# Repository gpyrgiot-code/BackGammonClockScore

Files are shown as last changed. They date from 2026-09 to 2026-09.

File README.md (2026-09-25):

# Backgammon Match Clock

A portable ESP32-S3 backgammon match clock and scoreboard built for an Elecrow
CrowPanel 5-inch 800x480 RGB touchscreen. The firmware combines tournament
scoring, three clock systems, Crawford tracking, physical controls, battery
monitoring, an RTC, player customization, match history, and day/night themes.

## Highlights

- 800x480 capacitive touchscreen interface
- Two player clocks and touch-adjustable scores
- Physical Player A, Player B, and Play/Pause buttons
- Match targets from 1 through 21 points (odd values)
- Timer by game or timer for the complete match
- Simple delay, Bronstein delay, and Fischer increment
- Crawford and post-Crawford tracking
- Standard score or Points to Win display
- Editable player names and checker-color scorecards
- Persistent settings stored in ESP32 preferences
- Match history with names, score, and RTC date
- MAX17048 battery monitoring and DS3231 date/time
- Day and night display themes
- Light-red timer warning at 1:30 or less
- Optimized custom GFX fonts and startup splash image

## Target Hardware

The firmware targets the Elecrow ESP32-S3 CrowPanel HMI with:

- ESP32-S3
- 8 MB OPI PSRAM
- 800x480 RGB-parallel display
- GT911 capacitive touch controller
- PCA9557 onboard I/O expander

External hardware used by the complete build:

- PCF8575 16-bit I2C GPIO expander
- MAX17048 LiPo fuel gauge
- DS3231 real-time clock
- Three normally-open momentary push buttons
- One-cell LiPo battery and a suitable protected charging/power circuit

The MAX17048 measures the battery but does not charge it. Use a charging and
power-management circuit designed for the battery chemistry and load. Verify
battery polarity before applying power; reversing BAT+ and BAT- can damage the
module, battery, or ESP32.

## Project Layout

```text
BackgammonMatchClock/
   |-- BackgammonMatchClock.ino
   |-- splash_image.h
   |-- splash4.png
   |-- 7segment48pt7b_numbers.h
   |-- collegeb96pt7b_numbers.h
   |-- FreeSansBold48pt7b_numbers.h
   |-- FreeSans12pt7b.h
```

The firmware uses a custom RGB565 renderer built on the ESP-IDF RGB LCD
peripheral. It does not require LVGL or an external TFT library.

## I2C Bus

The shared I2C bus uses:

| Signal | ESP32-S3 pin |
|---|---:|
| SDA | GPIO 19 |
| SCL | GPIO 20 |
| Logic supply | 3.3 V |
| Ground | GND |

Configured devices:

| Device | Address | Purpose |
|---|---:|---|
| PCA9557 | `0x18`-`0x1F` | CrowPanel initialization/reset control |
| PCF8575 | `0x20`-`0x27` | Physical clock buttons |
| MAX17048 | `0x36` | Battery voltage and state of charge |
| GT911 | Usually `0x5D` | Capacitive touch |
| DS3231 | `0x68` | Date and time |

All I2C modules share SDA, SCL, 3.3 V, and GND. An I2C splitter is only a
parallel connection hub; each device remains on the same bus and needs a unique
address.

## Physical Buttons

The PCF8575 ports are active-low inputs. Connect one terminal of each
normally-open button to its PCF8575 port and the other terminal to GND.

| Function | PCF8575 port |
|---|---:|
| Play/Pause | P00 |
| Player A clock | P01 |
| Player B clock | P07 |

Four-leg tactile switches contain two internally connected pairs. Use one leg
from each opposite electrical side. Confirm continuity with a multimeter before
soldering.

The firmware also supports a direct button on GPIO 38 for compatibility with the
earlier one-button prototype.

## Display Connections

The built-in RGB panel uses these fixed signals:

| Signal | GPIO |
|---|---|
| Backlight | 2 |
| D0-D15 | 8, 3, 46, 9, 1, 5, 6, 7, 15, 16, 4, 45, 48, 47, 21, 14 |
| DE | 40 |
| VSYNC | 41 |
| HSYNC | 39 |
| PCLK | 0 |

Do not reuse these pins for external controls.

## User Interface

### Main screen

The main screen contains:

- Battery status, elapsed match time, date, and time
- Player names and clock values
- Player scorecards
- Play Game/Pause Game control
- End Game and End Match controls
- Match target, game counter, and Crawford state
- Log and Settings buttons

The name bars use each player's selected checker color. When either timer reaches
1:30, its background becomes light red as a low-time warning.

### Touch controls

- Tap Player A's timer to finish A's turn and start Player B's clock.
- Tap Player B's timer to finish B's turn and start Player A's clock.
- Tap Play Game to start or resume; tap Pause Game to pause.
- Swipe up on a scorecard to add one point.
- Swipe down on a scorecard to remove one point.
- Tap a player name while paused to edit the name and checker color.
- Tap End Game to stop the current game without resetting the match clocks.
- Tap End Match to confirm and record the result.
- After a match ends, End Match becomes Reset.

Scores can only be changed while the clock is paused or after a game ends.

### Settings

Settings includes:

- Match target: 1, 3, 5, ... 21
- Time per game in 30-second steps
- Bonus or delay duration
- Timer scope: Game or Match
- Timing mode: Simple, Bronstein, or Fischer
- Appearance
- RTC clock/date setup
- Start Match and End Match

### Appearance

Appearance currently provides:

- Night or Day color theme
- Score or Points to Win display

Points to Win is a display-only calculation:

```text
points to win = match target - actual player score
```

Stored scores, Crawford logic, match winner detection, and history remain based
on the actual score.

### Match log

The Log screen stores up to eight completed matches. Each entry includes the RTC
date, both player names, and the final score. The log is stored in nonvolatile
ESP32 preferences and can be cleared from the Log screen.

## Timing Modes

### Simple delay

The reserve clock does not visibly decrease during the delay. Only time used
beyond the configured delay is deducted.

```text
deduction = max(0, elapsed turn time - delay)
```

Unused delay is not added to the reserve.

### Bronstein delay

The clock counts down immediately. When the player presses the clock, elapsed
time up to the configured delay is refunded. The final reserve deduction is the
same as Simple delay, but the live display behaves differently.

```text
refund = min(elapsed turn time, delay)
```

### Fischer increment

The clock counts down during the turn. Pressing the clock adds the configured
increment to that player's reserve.

```text
new reserve = old reserve - elapsed turn time + increment
```

Players can gain reserve time by moving faster than the increment.

### Timer scope

- **Game:** each player's timer resets when a new game begins.
- **Match:** each player's initial reserve equals time per game multiplied by
  the match target and carries across games.

If a player reaches zero, the timeout screen identifies that player. Applying
the penalty point remains a manual scoring action.

## Crawford Rule

When either player reaches one-away and Crawford has not already been used, the
next game is marked `CRAWFORD` and the doubling cube is disabled. After that
game, the display changes to `POST CRAWFORD` and the cube is enabled for all
remaining games.

## Fonts and Splash Image

The sketch uses trimmed GFX font headers to reduce flash use:

- `7segment48pt7b_numbers.h`: timer digits and colon
- `collegeb96pt7b_numbers.h`: score digits
- `FreeSansBold48pt7b_numbers.h`: match target digits
- `FreeSans12pt7b.h`: interface text

The splash image is stored as RGB565 data in `splash_image.h`. Its source is
`splash4.png`.

## Building with Arduino IDE

### Requirements

- Arduino IDE 2.x
- Espressif Systems ESP32 board package
- USB data cable

Open:

```text
BackgammonMatchClock/BackgammonMatchClock.ino
```

Recommended board settings:

| Setting | Value |
|---|---|
| Board | ESP32S3 Dev Module |
| PSRAM | OPI PSRAM |
| USB CDC On Boot | Disabled or Default |
| USB Mode | Hardware CDC/JTAG or Default |
| Upload Speed | 115200 |

PSRAM is mandatory. An 800x480 RGB565 framebuffer requires more memory than the
ESP32-S3's internal RAM can provide. If Serial Monitor reports `PSRAM found: no`,
select OPI PSRAM and upload again.

### Upload

1. Connect the CrowPanel over USB.
2. Select its `/dev/cu.usbserial...` port.
3. Compile and upload.
4. Open Serial Monitor at 115200 baud.

If automatic upload does not begin, hold BOOT, start the upload, and release BOOT
when `Connecting...` appears. Press RESET after a successful upload if needed.

Uploads at 921600 can connect successfully and then fail with `The chip stopped
responding`. Use 115200 for reliable flashing.

## Arduino CLI

From the repository directory:

```sh
sh scripts/compile-arduino.sh
sh scripts/upload-arduino.sh /dev/cu.usbserial-XXXXX
```

Replace the port with the result from:

```sh
arduino-cli board list
```

The equivalent compile target is:

```sh
arduino-cli compile \
  --fqbn esp32:esp32:esp32s3:PSRAM=opi,CDCOnBoot=default,USBMode=default \
  BackgammonMatchClock
```

## PlatformIO

The repository includes `platformio.ini`:

```sh
pio run
pio run -t upload
pio device monitor -b 115200
```

Arduino IDE/CLI is the primary tested workflow for the CrowPanel hardware.

## Wokwi

`WokwiMatchClock` is a generated compatibility target. Wokwi does not model the
CrowPanel RGB panel, GT911, PCA9557, PCF8575, MAX17048, or DS3231 exactly, so it
uses display and input substitutions.

After firmware changes, regenerate the Wokwi copy with:

```sh
node scripts/sync-wokwi.mjs
```

Do not place both the generated `sketch.ino` and hardware `.ino` in one Wokwi
project because Arduino will compile both and report duplicate definitions.

The ESP32 binary cannot run directly on macOS because it contains ESP32-S3
machine code and hardware drivers. A native desktop simulator is not yet
included.

## Serial Diagnostics

Use Serial Monitor at 115200 baud. A healthy boot should report:

- `PSRAM found: yes`
- PCA9557 found and initialized
- PCF8575 found, if connected
- MAX17048 found at `0x36`, if connected
- DS3231 found at `0x68`, if connected
- GT911 found, normally at `0x5D`
- `esp_lcd_new_rgb_panel: 0`
- `esp_lcd_panel_reset: 0`
- `esp_lcd_panel_init: 0`

P00 Play/Pause presses also print a diagnostic line with the current mode and
clock state.

## Troubleshooting

### White or blank screen

- Confirm PSRAM is set to OPI PSRAM.
- Verify Serial reports `PSRAM found: yes`.
- Confirm the RGB panel initialization calls return `0`.
- Use a stable USB power source and cable.
- Check that the PCA9557 appears on the I2C scan.

### Touch is not detected

- Confirm the GT911 appears in the I2C scan.
- Check SDA, SCL, power, and ground.
- Make sure no external device is holding the shared I2C bus low.

### PCF8575 buttons are not detected

- Confirm the expander appears between `0x20` and `0x27`.
- Connect each button between its assigned P port and GND.
- Solder module headers; loose unsoldered pins are not electrically reliable.
- Verify address jumpers do not conflict with another device.

### Battery percentage is missing or unstable

- Confirm the MAX17048 appears at `0x36`.
- Verify battery polarity and solder joints.
- Allow the gauge time to settle after reconnecting the cell.
- The firmware performs a MAX17048 quick-start during initialization.
- Charging may be inferred from a rising voltage/state-of-charge trend unless a
  dedicated charger status pin is added.

### RTC is missing or the log says DATE UNSET

- Confirm the DS3231 appears at `0x68`.
- Set date and time through Settings > Clock.
- Check the RTC backup battery if time is lost when power is removed.

### Upload fails after changing baud rate

Select 115200 upload speed, reconnect USB, and retry. Temporarily disconnecting
external modules can help diagnose power or bus issues while flashing.

### Duplicate or unreadable Serial output

The firmware writes diagnostics to both available serial interfaces for board
compatibility. Use 115200 baud. Boot ROM characters may briefly appear garbled
if the monitor opens during reset.

## Enclosure

The `BackgammonMatchClock/case` directory contains enclosure work for a sloped
desktop clock body with a front display opening and top-mounted player and
Play/Pause buttons. Verify dimensions against the physical hardware before
printing or machining.

## Safety

- Use a protected single-cell LiPo setup designed for charging and load sharing
  if the clock operates while charging.
- Never connect a LiPo directly to a 5 V input unless the board documentation
  explicitly permits it.
- Do not reverse battery polarity.
- Do not power I2C signal pull-ups above 3.3 V.
- Place a physical power switch in the battery or regulated load path according
  to the charger/power-path design.

## Current Status

The firmware compiles for ESP32-S3 with OPI PSRAM and currently uses about 47%
of program flash and 7% of internal dynamic memory. The project remains under
active development, with Appearance prepared for additional layouts and themes.

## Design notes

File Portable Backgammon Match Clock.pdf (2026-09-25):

# Portable Backgammon Match Clock

# Current Firmware Code Walkthrough

# ESP32-S3 CrowPanel 5-inch / 800x480 / GT911

Source | BackgammonMatchClock.ino
Source size | 4,357 lines at publication
Firmware label | lcd-refresh-2026-06-07
Manual edition | September 2026 update

Hardware, wiring, state model, timing rules, UI, persistence, diagnostics, and complete source

Backgammon Match Clock | Current Firmware Walkthrough

# Contents

1 Purpose and Scope | 3
2 System Architecture | 3
3 Hardware Contract | 4
4 State Model | 5
5 Clock Engine | 5
6 Scoring and Match Lifecycle | 6
7 User Interface | 6
8 Touch and Button Input | 7
9 Rendering Pipeline | 7
10 Battery, Charging, and RTC | 8
11 Persistence and Match Log | 8
12 Startup and Diagnostics | 8
13 Build and Upload | 8

14 Maintenance Guide | 9
15 Known Limitations | 9
16 Top-Level Function Inventory | 10
A Complete Current Firmware Source | 11

# 1 Purpose and Scope

This document explains the current portable backgammon match clock firmware as an engineering and maintenance reference. It supersedes the earlier V2.0 PDF, whose source snapshot was 4,104 lines and predated several user-interface and hardware changes. The present sketch is a single Arduino translation unit with custom display, touch, game, timing, persistence, and peripheral code.

## The clock provides:

- two player clocks, scores, editable names, and checker colors;
- touch control plus Player A, Player B, and Play/Pause physical buttons;
- Simple delay, Bronstein delay, and Fischer increment;
- timer-by-game and timer-by-match scopes;
- Crawford and post-Crawford match state;
- day/night themes and Score/Points-to-Win views;
- a MAX17048 fuel gauge, DS3231 RTC, and eight-entry match log;

## - a compiled RGB565 splash image and optimized numeric fonts; and

- direct ESP-IDF RGB-panel rendering without LVGL.

# 2 System Architecture

The firmware uses an event-and-state architecture. Input handlers mutate the model, model transitions mark the display dirty, and rendering rebuilds the appropriate screen. Time-sensitive timer regions can be refreshed separately from the rest of the interface.

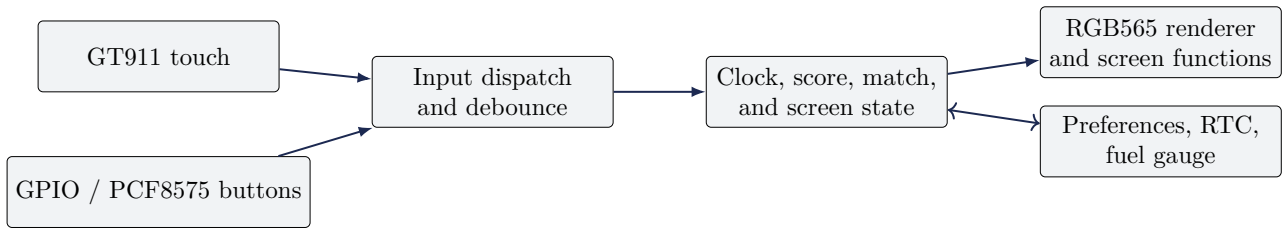
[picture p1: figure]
GT911 touch; GPIO / PCF8575 buttons; Input dispatch and debounce; Clock, score, match, and screen state; RGB565 renderer and screen functions; Preferences, RTC, fuel gauge

# 2.1 Main runtime cycle

setup() initializes serial diagnostics, button objects, I2C peripherals, the RGB panel, splash screen, preferences, match state, and RTC cache. The order is deliberate: the onboard PCA9557 and touch-reset path must be ready before the GT911 and display are used.

## loop() performs five recurring jobs:

1. poll touch and physical buttons;
2. update the active clock when in match mode;
3. commit delayed preference writes;

## 4. evaluate inactivity sleep; and

5. refresh either the whole screen or only the timer panels.

The one-second timer refresh and dirty-screen redraw split reduces visible flashing compared with repainting the entire 800x480 framebuffer continuously.

# 3 Hardware Contract

# 3.1 Target board

The target is the Elecrow CrowPanel ESP32-S3 5-inch HMI with an 800x480 RGB-parallel panel, GT911 capacitive touch controller, onboard PCA9557, and 8 MB OPI PSRAM. PSRAM is mandatory because a full RGB565 frame requires approximately 768,000 bytes before additional buffers and application state.

# 3.2 Shared I2C bus

Device or signal | Pin/address | Purpose
SDA | GPIO 19 | Shared data line; use 3.3 V pull-ups only.
SCL | GPIO 20 | Shared clock line.
PCA9557 | 0x18-0x1F | CrowPanel reset and board initialization.
PCF8575 | 0x20-0x27 | Three active-low physical buttons.
MAX17048 | 0x36 | Single-cell battery voltage and state of charge.
GT911 | normally 0x5D | Capacitive touch coordinates.
DS3231 | 0x68 | Date and time for the status bar and match log.

All devices share SDA, SCL, 3.3 V, and GND. A passive I2C splitter duplicates connectors; it does not create separate buses or resolve address conflicts.

# 3.3 Physical buttons

The PCF8575 is initialized with all port bits high. Each normally-open switch connects its assigned port to ground when pressed.

Function | PCF8575 port | Runtime action
Play/Pause | P00 | Start a game, pause, or resume.
Player A | P01 | End A’s turn and start B’s clock.
Player B | P07 | End B’s turn and start A’s clock.

GPIO 38 remains as compatibility support for the earlier single-button wiring. The direct Player B and score/menu pins use 255, which is the sketch’s disabled-pin sentinel.

# 3.4 RGB display pins

Role | GPIO assignment
D0-D15 | 8, 3, 46, 9, 1, 5, 6, 7, 15, 16, 4, 45, 48, 47, 21, 14
DE / VSYNC / HSYNC / PCLK | 40 / 41 / 39 / 0
Backlight | 2

These pins belong to the panel and must not be reused by external controls. The firmware requests a 20 MHz pixel clock and ten-line bounce buffer.

# 4 State Model

# 4.1 Device modes

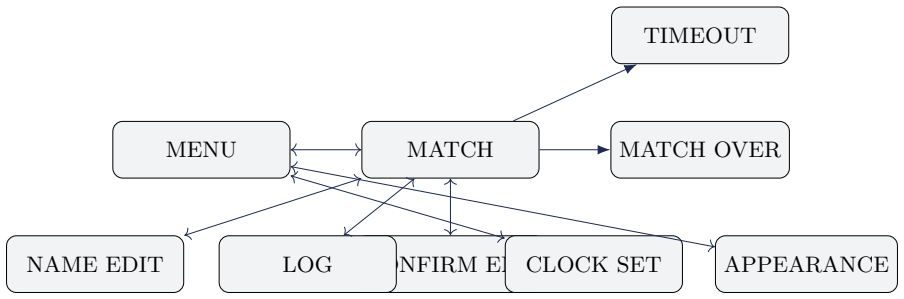
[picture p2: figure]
MENU; MATCH; MATCH OVER; TIMEOUT

NAME EDIT | LOG | CONFIRM ENDCLOCK SET | APPEARANCE

DeviceMode prevents a touch or physical-button event intended for one screen from mutating another. Modal views such as name editing, RTC setup, and end-match confirmation therefore have their own drawing and tap handlers.

# 4.2 Core match state

Scores, reserve times, active player, running/paused state, game number, Crawford flags, winner, and timeout player are stored independently. This is important: game_number advances only in startNewGame(), not when a score is manually corrected.

The valid match targets are all odd values from 1 to 21. Scores clamp to the range zero through the target, and match completion occurs at score >= match_target; there is no off-by-one requirement.

# 5 Clock Engine

Each player’s stored reserve is milliseconds. turnStartMs identifies the beginning of the active turn. A pause records pausedTurnElapsedMs; a resume reconstructs the original turn start, so the displayed and ultimately charged time continue exactly from the pause point.

Let R be reserve time, E elapsed turn time, and D the configured delay or increment.

# 5.1 Simple delay

## The display holds steady during the delay. At turn end:

## Rnew = R − max(0, E − D)

Unused delay is discarded.

# 5.2 Bronstein delay

The active display counts down immediately. At turn end, up to D is refunded, which is equivalent to:

## Rnew = R − max(0, E − D)

The distinction from Simple delay is visual during the turn, not the final reserve deduction.

# 5.3 Fischer increment

## Elapsed time is deducted and a fixed increment is added:

## Rnew = R − E + D

A fast move can therefore increase the player’s reserve.

# 5.4 Game and match timer scope

In Game scope, a new game resets both reserves to the configured time per game. In Match scope, the initial reserve is:

## starting seconds = time per game × match target

and carries across games. Reaching zero stops the clock, records the timed-out player, ends the current game, and displays the timeout state. The score penalty is intentionally entered manually.

# 6 Scoring and Match Lifecycle

Score changes are accepted only while the clock is paused or in timeout state. A positive change during a running game first calls endCurrentGame(). Negative changes are treated as corrections and do not advance game or Crawford state.

# 6.1 Game controls

Play Game Starts a new game or resumes a paused turn.
Pause Game Preserves current reserves and elapsed turn state.
End Game Stops the current game without resetting match clocks or scores.
End Match Opens a confirmation dialog. Confirmation records the current leader and score. Reset Replaces End Match after completion and clears the active match state.

# 6.2 Crawford and post-Crawford

When a player first reaches one-away, the next game is marked Crawford. During that game the doubling cube is disabled. Completion of the Crawford game sets crawford_used, clears the active flag, enables the cube, and enters post-Crawford state. The implementation also recognizes the practical case in which the opponent’s score changes during the Crawford game.

# 7 User Interface

# 7.1 Main-screen geometry

The screen is partitioned into explicit Rect values. Player columns are 228 pixels wide, the center controls are 290 pixels wide, and the 34-pixel status bar spans the top. Large touch hit rectangles extend beyond visible button edges to improve usability.

Battery / elapsed / date / time

Player A name

Player A timer

Player A score

Play / Pause

End Game End Match

Target / game / Crawford

Log | Settings

Player B name

Player B timer

Player B score

# 7.2 Appearance

Night mode uses the original black background. Day mode uses a medium-gray overall background and very-light-gray neutral panels while leaving the status bar dark. Player name bars always use the selected player color with white text.

The score view can show either actual Score or Points to Win. Points to Win is display-only: stored scores, Crawford detection, winner detection, and logs all continue to use actual points.

The active timer uses a darker emphasis treatment. Any reserve at or below 90 seconds receives a light-red timer background. Audible warnings begin at 30 seconds and become more frequent at 10 seconds.

The match-target panel also communicates Crawford state. Crawford uses a light-pink panel with black target/game text and a dark-yellow CRAWFORD label. Post-Crawford uses a light-blue panel with black target/game text and a dark-orange POST CRAWFORD label.

# 7.3 Fonts

## The sketch includes optimized numeric-only GFX fonts:

- 7segment48pt7b_numbers.h for timer digits and colon;
- collegeb96pt7b_numbers.h for player scores;

## - FreeSansBold48pt7b_numbers.h for the match target; and

- FreeSans12pt7b.h for general interface text.

Fallback branches allow compilation when an optional font header is absent, but the intended visual result requires the project-local headers.

# 8 Touch and Button Input

The GT911 status register is polled and acknowledged after each data-ready report. Touch coordinates are transformed into the 800x480 orientation and clamped. The handler tracks start, last, minimum, and maximum positions plus a release grace period. This supports reliable taps and vertical score swipes.

The button code debounces both direct GPIO and PCF8575 inputs. During a running turn, only the active player’s own clock button can end the turn. Pressing the inactive player’s side is ignored, preventing an accidental bump from restarting the delay window.

# 9 Rendering Pipeline

CrowPanelRGBDisplay provides the subset of familiar GFX operations used by the application. It wraps the ESP-IDF RGB panel, an RGB565 framebuffer, and a line buffer. Drawing includes fills, outlines, text, scaled GFX glyphs, and image copying.

## The renderer has two update paths:

- drawDisplay() paints the complete current screen after state or mode changes.
- drawTimerPanels() repaints only the two timer regions on the one-second clock cadence.

This division is central to controlling flicker on the RGB panel. New features should call markDisplayDirty() only when a complete redraw is needed.

# 10 Battery, Charging, and RTC

# 10.1 MAX17048

The firmware detects the gauge at 0x36, reads its version, issues a quick-start command, and reads cell voltage and state of charge. The displayed percentage is clamped to zero through 100. The MAX17048 measures the cell; it is not a charger.

If no dedicated active-low charger status pin is configured, the lightning bolt is inferred from a sustained upward voltage or state-of-charge trend. This is an estimate, so a connected charger can be missed near full charge and transient battery recovery can occasionally resemble charging.

# 10.2 DS3231

The RTC supplies date/time for the status bar and log. Clock Settings edits year, month, day, hour, and minute, clamps the day for the selected month, and writes BCD registers. Invalid or unset dates appear as DATE UNSET.

# 11 Persistence and Match Log

ESP32 Preferences uses namespace bgclock. Persisted values include target, time, delay, increment, brightness, timing mode, timer scope, display theme, score view, names, player colors, and up to eight log entries.

General settings use a 1.5-second delayed write to reduce flash wear while a control is tapped repeatedly. Names and colors are saved when editing is confirmed. Each completed match log entry contains date, names, and score.

# 12 Startup and Diagnostics

## The expected healthy serial sequence includes:

- PSRAM found: yes;
- PCA9557 initialization;
- optional PCF8575 at 0x20-0x27;
- optional MAX17048 at 0x36;
- optional DS3231 at 0x68;

## - GT911, usually at 0x5D; and

- zero return values from RGB panel creation, reset, and initialization.

The current startup goes directly to the compiled splash4.png image via splash_image.h; the former arcade-style diagnostic loading screen has been removed.

# 13 Build and Upload

## Arduino IDE settings:

Setting | Value
Board | ESP32S3 Dev Module
PSRAM | OPI PSRAM
Upload speed | 115200
Serial monitor | 115200 baud

The 800x480 framebuffer cannot be allocated if PSRAM is disabled; the usual symptoms are no mem for frame buffer and a white screen. Uploads at 921600 have also stopped responding on this unit, so 115200 is the reliable setting.

## Repository helper commands:

## sh scripts/compile-arduino.sh sh scripts/upload-arduino.sh /dev/cu.usbserial-XXXXX

# 14 Maintenance Guide

# 14.1 Adding a new setting

Add model state and a default, render its control, handle its tap, validate it in loadSettings(), write it in saveSettingsIfNeeded(), and call markSettingsDirty() after changes. If it affects the active match, decide explicitly whether it is allowed mid-game.

# 14.2 Adding a new screen

Add a DeviceMode, drawing function, hit rectangles, and mode-specific tap branch. Ensure physical buttons either have a meaningful action or return without mutating match state. Set the destination mode and mark the display dirty on every entry and exit.

# 14.3 Changing fonts

Keep the exported symbol name synchronized with the include and drawing call. Numeric-only trimming saves substantial flash, but the glyph range and lookup indices must remain valid. Compile immediately after replacing a generated header and verify timer, score, and target independently.

# 14.4 Changing panel timing

Treat pixel-clock and sync changes as hardware changes. Test splash and static screens as well as timer updates; a setting that seems stable on a simple fill can still show tearing with image data. Keep OPI PSRAM enabled.

# 15 Known Limitations

- Charging status is inferred unless a charger STAT signal is wired.
- Match logs are capped at eight entries and use Preferences rather than a filesystem.
- Scores and timeout penalties remain intentionally manual.
- The UI uses fixed 800x480 coordinates and is not resolution-independent.
- The single-file sketch is approachable but increasingly large; future maintenance would benefit from separating hardware, match logic, and screens.

# 16 Top-Level Function Inventory

Function group | Responsibility
setup, loop | Initialization and cooperative runtime scheduling.
handleButtons, handleTouch | Debounce, gesture recognition, and input dispatch.
pauseClock, resumeClock, switchClockTo | Turn and pause lifecycle.
applyTurnElapsed, visibleReserveMs | Timing-mode accounting and live display value.
adjustScore, checkMatchState | Legal score updates and winner detection.
startNewGame, endCurrentGame | Explicit game counter and per-game reset boundary.
markCrawfordUsed | Crawford to post-Crawford transition.
forceEndMatch, resetMatch | Manual match completion and clean restart.
drawDisplay, drawTimerPanels | Full and partial rendering entry points.
drawNameEditor, drawMatchLog | Player customization and history views.
drawClockSettings | RTC editor.
drawAppearanceSettings | Theme and score-view editor.
initCrowPanelExpander, initTouch | Board and GT911 setup.
initButtonExpander | PCF8575 discovery and initialization.
initFuelGauge, initRtcClock | Optional battery and time peripherals.
loadSettings, saveSettingsIfNeeded | Preferences validation and delayed commits.
recordMatchLog, clearMatchLog | Persistent result history.
maybeSleep, setBrightness | Power-facing display behavior.

# A Complete Current Firmware Source

This appendix is included directly from the project sketch at LaTeX build time. Its line numbers therefore correspond to the exact source used to generate this edition.

1 | /*
2 | Portable Backgammon Match Clock and Scoreboard
3 | Target: Elecrow CrowPanel ESP32 HMI 5.0-inch display (DIS07050H)

4
5 | Display library:
6 | This sketch uses the ESP32-S3 RGB LCD peripheral for the built-in 800x480
7 | RGB-parallel panel.

8
9 | Clock model:
10 | - At the start of each game, no clock is running.
11 | - Pressing Player A’s large button ends A’s turn and starts B’s clock.
12 | - Pressing Player B’s large button ends B’s turn and starts A’s clock.
13 | - Optional delay/increment is supported. Delay is Bronstein/simple delay:
14 | main time does not tick down until the active turn exceeds delaySeconds.
15 | - Increment, if enabled, is added to the player whose turn was ended.

16
17 | Crawford model:
18 | - When either player reaches match_target - 1 and Crawford has not been used,
19 | the following game is marked Crawford and the cube is disabled.
20 | - After that game ends, all later games are post-Crawford and cube is enabled.
21 | */

22
23 | #include <Arduino.h>
24 | #include <Wire.h>
25 | #include <stdarg.h>
26 | #include <Preferences.h>
27 | #include <esp_sleep.h>
28 | #include <esp_heap_caps.h>
29 | #include <esp_lcd_panel_ops.h>
30 | #include <esp_lcd_panel_rgb.h>
31 | #include "splash_image.h"

32
33 | #if __has_include(<gfxfont.h>)
34 | #include <gfxfont.h>
35 | #else
36 | typedef struct {
37 | uint16_t bitmapOffset;
38 | uint8_t width;
39 | uint8_t height;
40 | uint8_t xAdvance;
41 | int8_t xOffset;
42 | int8_t yOffset;
43 | } GFXglyph;

44
45 | typedef struct {
46 | uint8_t *bitmap;
47 | GFXglyph *glyph;
48 | uint16_t first;
49 | uint16_t last;
50 | uint16_t yAdvance;
51 | } GFXfont;
52 | #endif

53
54 | #if __has_include("7segment48pt7b_numbers.h")
55 | #include "7segment48pt7b_numbers.h"
56 | #define BGMC_HAS_CLOCK_FONT 1
57 | #define BGMC_CLOCK_FONT SevenSegment48pt7bNumbers
58 | #elif __has_include("Seven_Segment48pt7b_numbers.h")
59 | #include "Seven_Segment48pt7b_numbers.h"
60 | #define BGMC_HAS_CLOCK_FONT 1
61 | #define BGMC_CLOCK_FONT Seven_Segment48pt7bNumbers
62 | #elif __has_include("Seven_Segment48pt7b.h")
63 | #include "Seven_Segment48pt7b.h"
64 | #define BGMC_HAS_CLOCK_FONT 1
65 | #define BGMC_CLOCK_FONT Seven_Segment48pt7b
66 | #elif __has_include("Seven_Segment24pt7b.h")
67 | #include "Seven_Segment24pt7b.h"
68 | #define BGMC_HAS_CLOCK_FONT 1
69 | #define BGMC_CLOCK_FONT Seven_Segment24pt7b
70 | #elif __has_include("FreeMonoBold24pt7b.h")
71 | #include "FreeMonoBold24pt7b.h"
72 | #define BGMC_HAS_CLOCK_FONT 1
73 | #define BGMC_CLOCK_FONT FreeMonoBold24pt7b
74 | #elif __has_include(<Fonts/FreeMonoBold24pt7b.h>)
75 | #include <Fonts/FreeMonoBold24pt7b.h>
76 | #define BGMC_HAS_CLOCK_FONT 1
77 | #define BGMC_CLOCK_FONT FreeMonoBold24pt7b
78 | #else
79 | #define BGMC_HAS_CLOCK_FONT 0

80 #endif

81
82 | #if __has_include("FreeSans18pt7b.h")
83 | #include "FreeSans18pt7b.h"
84 | #define BGMC_HAS_UI_FONT 1
85 | #elif __has_include(<Fonts/FreeSans18pt7b.h>)
86 | #include <Fonts/FreeSans18pt7b.h>
87 | #define BGMC_HAS_UI_FONT 1
88 | #else
89 | #define BGMC_HAS_UI_FONT 0
90 | #endif

91
92 | #if __has_include("FreeSans12pt7b.h")
93 | #include "FreeSans12pt7b.h"
94 | #define BGMC_HAS_SMALL_UI_FONT 1
95 | #elif __has_include(<Fonts/FreeSans12pt7b.h>)
96 | #include <Fonts/FreeSans12pt7b.h>
97 | #define BGMC_HAS_SMALL_UI_FONT 1
98 | #else
99 | #define BGMC_HAS_SMALL_UI_FONT 0
100 | #endif

101
102 | #if __has_include("FreeSansBold96pt7b.h")
103 | #include "FreeSansBold96pt7b.h"
104 | #define BGMC_HAS_SCORE_96_FONT 1
105 | #elif __has_include(<Fonts/FreeSansBold96pt7b.h>)
106 | #include <Fonts/FreeSansBold96pt7b.h>
107 | #define BGMC_HAS_SCORE_96_FONT 1
108 | #else
109 | #define BGMC_HAS_SCORE_96_FONT 0
110 | #endif

111
112 | #if __has_include("collegeb96pt7b_numbers.h")
113 | #include "collegeb96pt7b_numbers.h"
114 | #define BGMC_HAS_COLLEGE_SCORE_FONT 1
115 | #define BGMC_COLLEGE_SCORE_FONT collegeb96pt7bNumbers
116 | #elif __has_include("college96pt7b_numbers.h")
117 | #include "college96pt7b_numbers.h"
118 | #define BGMC_HAS_COLLEGE_SCORE_FONT 1
119 | #define BGMC_COLLEGE_SCORE_FONT college96pt7bNumbers
120 | #elif __has_include("collegeb96pt7b.h")
121 | #include "collegeb96pt7b.h"
122 | #define BGMC_HAS_COLLEGE_SCORE_FONT 1
123 | #define BGMC_COLLEGE_SCORE_FONT collegeb96pt7b
124 | #else
125 | #define BGMC_HAS_COLLEGE_SCORE_FONT 0
126 | #endif

127
128 | #if __has_include("FreeSansBold48pt7b_numbers.h")
129 | #include "FreeSansBold48pt7b_numbers.h"
130 | #define BGMC_HAS_MATCH_TARGET_48_FONT 1
131 | #define BGMC_MATCH_TARGET_48_FONT FreeSansBold48pt7bNumbers
132 | #elif __has_include("FreeSansBold48pt7b.h")
133 | #include "FreeSansBold48pt7b.h"
134 | #define BGMC_HAS_MATCH_TARGET_48_FONT 1
135 | #define BGMC_MATCH_TARGET_48_FONT FreeSansBold48pt7b
136 | #elif __has_include(<Fonts/FreeSansBold48pt7b.h>)
137 | #include <Fonts/FreeSansBold48pt7b.h>
138 | #define BGMC_HAS_MATCH_TARGET_48_FONT 1
139 | #define BGMC_MATCH_TARGET_48_FONT FreeSansBold48pt7b
140 | #else
141 | #define BGMC_HAS_MATCH_TARGET_48_FONT 0
142 | #endif

143
144 | #if __has_include("FreeSansBold24pt7b.h")
145 | #include "FreeSansBold24pt7b.h"
146 | #define BGMC_HAS_SCORE_FONT 1
147 | #elif __has_include(<Fonts/FreeSansBold24pt7b.h>)
148 | #include <Fonts/FreeSansBold24pt7b.h>
149 | #define BGMC_HAS_SCORE_FONT 1
150 | #else
151 | #define BGMC_HAS_SCORE_FONT 0
152 | #endif

153
154 | // ---------------------------------------------------------------------------
155 | // DIS07050H display-first pin map. External buttons can be added later on
156 | // available expansion pins; avoid the LCD RGB bus pins below.
157 | // ---------------------------------------------------------------------------
158 | static const uint8_t PIN_PLAYER_A_BUTTON = 38; // GPIO_D IO38: one-button clock toggle to GND.
159 | static const uint8_t PIN_PLAYER_B_BUTTON = 255;
160 | static const uint8_t PIN_SCORE_A_PLUS = 255;
161 | static const uint8_t PIN_SCORE_A_MINUS = 255;
162 | static const uint8_t PIN_SCORE_B_PLUS = 255;
163 | static const uint8_t PIN_SCORE_B_MINUS = 255;
164 | static const uint8_t PIN_MENU_SELECT = 255;
165 | static const uint8_t PIN_MENU_UP = 255;

166 | static const uint8_t PIN_MENU_DOWN = 255;
167 | static const uint8_t PIN_BUZZER = 255;
168 | static const uint8_t PIN_TFT_BACKLIGHT = 2;
169 | static const uint8_t PIN_BATTERY_ADC = 255;
170 | static const uint8_t PIN_CHARGE_DETECT = 255; // Optional charger STAT pin, active-low when wired.

171
172 | static const uint16_t PANEL_WIDTH = 800;
173 | static const uint16_t PANEL_HEIGHT = 480;
174 | static const uint8_t PIN_LCD_D0 = 8;
175 | static const uint8_t PIN_LCD_D1 = 3;
176 | static const uint8_t PIN_LCD_D2 = 46;
177 | static const uint8_t PIN_LCD_D3 = 9;
178 | static const uint8_t PIN_LCD_D4 = 1;
179 | static const uint8_t PIN_LCD_D5 = 5;
180 | static const uint8_t PIN_LCD_D6 = 6;
181 | static const uint8_t PIN_LCD_D7 = 7;
182 | static const uint8_t PIN_LCD_D8 = 15;
183 | static const uint8_t PIN_LCD_D9 = 16;
184 | static const uint8_t PIN_LCD_D10 = 4;
185 | static const uint8_t PIN_LCD_D11 = 45;
186 | static const uint8_t PIN_LCD_D12 = 48;
187 | static const uint8_t PIN_LCD_D13 = 47;
188 | static const uint8_t PIN_LCD_D14 = 21;
189 | static const uint8_t PIN_LCD_D15 = 14;
190 | static const uint8_t PIN_LCD_DE = 40;
191 | static const uint8_t PIN_LCD_VSYNC = 41;
192 | static const uint8_t PIN_LCD_HSYNC = 39;
193 | static const uint8_t PIN_LCD_PCLK = 0;
194 | static const uint8_t PIN_I2C_SDA = 19;
195 | static const uint8_t PIN_I2C_SCL = 20;
196 | static const uint8_t PCF8575_PLAY_PAUSE_PIN = 0; // PCF8575 P00, button to GND.
197 | static const uint8_t PCF8575_PLAYER_A_PIN = 1; // PCF8575 P01, button to GND.
198 | static const uint8_t PCF8575_PLAYER_B_PIN = 7; // PCF8575 P07, button to GND.
199 | static const uint8_t MAX17048_I2C_ADDRESS = 0x36;
200 | static const uint8_t DS3231_I2C_ADDRESS = 0x68;

201
202 | // Rotary encoder placeholders. This sketch uses up/down buttons by default.
203 | static const uint8_t PIN_ENCODER_A = 255;
204 | static const uint8_t PIN_ENCODER_B = 255;

205
206 | // Battery divider calibration placeholders.
207 | static const float BATTERY_ADC_REF_VOLTS = 3.30f;
208 | static const float BATTERY_DIVIDER_RATIO = 2.00f; // Vbat = Vadc * ratio.
209 | static const float BATTERY_EMPTY_VOLTS = 3.30f;
210 | static const float BATTERY_FULL_VOLTS = 4.20f;

211
212 | // Display/backlight defaults.
213 | static const uint8_t DEFAULT_BRIGHTNESS = 210; // 0..255 PWM duty.
214 | static const bool TFT_BACKLIGHT_ACTIVE_HIGH = true;
215 | static const uint16_t ILI9341_BLACK = 0x0000;
216 | static const uint16_t ILI9341_WHITE = 0xFFFF;
217 | static const uint16_t ILI9341_RED = 0xF800;
218 | static const uint16_t ILI9341_GREEN = 0x07E0;
219 | static const uint16_t ILI9341_BLUE = 0x001F;
220 | static const uint16_t ILI9341_CYAN = 0x07FF;
221 | static const uint16_t ILI9341_YELLOW = 0xFFE0;
222 | static const uint16_t TFT_BACKGROUND = ILI9341_BLACK;
223 | static const uint16_t TFT_PANEL = 0x2104;
224 | static const uint16_t TFT_PANEL_ALT = 0x3186;
225 | static const uint16_t TFT_BORDER = 0x7BEF;
226 | static const uint16_t TFT_BUTTON_BORDER = 0xD6BA;
227 | static const uint16_t TFT_TEXT = ILI9341_WHITE;
228 | static const uint16_t TFT_TEXT_DARK = ILI9341_BLACK;
229 | static const uint16_t TFT_ACTIVE_TEXT = 0x4208;
230 | static const uint16_t TFT_MUTED = 0xBDF7;
231 | static const uint16_t TFT_ACCENT_A = ILI9341_CYAN;
232 | static const uint16_t TFT_ACCENT_B = 0xFD20;
233 | static const uint16_t TFT_MAGENTA = 0xF81F;
234 | static const uint16_t TFT_WARN = ILI9341_YELLOW;
235 | static const uint16_t TFT_DANGER = ILI9341_RED;
236 | static const uint16_t TFT_OK = ILI9341_GREEN;
237 | static const uint16_t TFT_TIMER_WARNING_BG = 0xFBCF; // Light red for the final 90 seconds.
238 | static const uint16_t TFT_CRAWFORD_BG = 0xFE5B; | // Light pink (#F8C8DC).
239 | static const uint16_t TFT_CRAWFORD_LABEL = 0xBC21; | // Dark yellow (#B8860B).
240 | static const uint16_t TFT_POST_CRAWFORD_BG = 0xAEDC; // Light blue (#ADD8E6).
241 | static const uint16_t TFT_POST_CRAWFORD_TEXT = 0xC2E0; // Dark orange (#C65D00).
242 | static const uint16_t PLAYER_COLOR_RED = 0x7800; | // #7C0A02 approximated in RGB565.
243 | static const uint16_t PLAYER_COLOR_BLUE = 0x194A; | // #1C2951 approximated in RGB565.
244 | static const uint16_t PLAYER_COLOR_GREEN = 0x19A5; | // #1C352D approximated in RGB565.
245 | static const uint16_t PLAYER_COLOR_YELLOW = 0xFD20; // #FFA700 approximated in RGB565.
246 | static const uint16_t PLAYER_COLOR_GRAY = 0x4208;
247 | static const uint16_t PLAYER_COLOR_WHITE = ILI9341_WHITE;

248
249 | // Time behavior.
250 | static const uint32_t DEFAULT_INITIAL_TIME_SECONDS = 15UL * 60UL;
251 | static const uint8_t DEFAULT_DELAY_SECONDS = 12;

252 | static const uint8_t DEFAULT_INCREMENT_SECONDS = 0;
253 | static const uint32_t LOW_TIME_WARNING_SECONDS = 30;
254 | static const uint32_t CRITICAL_TIME_WARNING_SECONDS = 10;
255 | static const uint32_t SLEEP_AFTER_IDLE_MS = 10UL * 60UL * 1000UL;
256 | static const uint32_t LCD_PIXEL_CLOCK_HZ = 20000000;
257 | static const uint16_t LCD_BOUNCE_BUFFER_LINES = 10;
258 | static const uint8_t PLAYER_NAME_MAX_LEN = 10;

259
260 | // Debounce intervals. Large buttons stay snappy; score/menu buttons are slower.
261 | static const uint16_t PLAYER_BUTTON_DEBOUNCE_MS = 25;
262 | static const uint16_t SMALL_BUTTON_DEBOUNCE_MS = 90;
263 | static const uint16_t DISPLAY_REFRESH_MS = 1000;
264 | static const uint16_t SETTINGS_SAVE_DELAY_MS = 1500;
265 | static const char *FIRMWARE_VERSION = "lcd-refresh-2026-06-07";
266 | static const uint8_t MATCH_LOG_MAX_ENTRIES = 8;

267
268 | void logLine(const char *message);
269 | void logPrintf(const char *format, ...);

270
271 | // ---------------------------------------------------------------------------
272 | // Types
273 | // ---------------------------------------------------------------------------
274 | enum Player : uint8_t {
275 | PLAYER_A = 0,
276 | PLAYER_B = 1,
277 | PLAYER_NONE = 255
278 | };

279
280 | enum TimingMode : uint8_t {
281 | SIMPLE_DELAY,
282 | BRONSTEIN_DELAY,
283 | FISCHER_INCREMENT
284 | };

285
286 | enum TimerScope : uint8_t {
287 | TIMER_BY_GAME,
288 | TIMER_BY_MATCH
289 | };

290
291 | enum DisplayTheme : uint8_t {
292 | THEME_NIGHT,
293 | THEME_DAY
294 | };

295
296 | enum ScoreDisplayMode : uint8_t {
297 | SCORE_STANDARD,
298 | SCORE_POINTS_TO_WIN
299 | };

300
301 | enum DeviceMode : uint8_t {
302 | MODE_MENU,
303 | MODE_MATCH,
304 | MODE_MATCH_OVER,
305 | MODE_TIMEOUT,
306 | MODE_NAME_EDIT,
307 | MODE_LOG,
308 | MODE_CLOCK_SET,
309 | MODE_APPEARANCE,
310 | MODE_CONFIRM_END_MATCH
311 | };

312
313 | enum MenuItem : uint8_t {
314 | MENU_MATCH_TARGET,
315 | MENU_INITIAL_TIME,
316 | MENU_DELAY,
317 | MENU_INCREMENT,
318 | MENU_BRIGHTNESS,
319 | MENU_START_MATCH,
320 | MENU_RESET_MATCH,
321 | MENU_COUNT
322 | };

323
324 | struct DebouncedButton {
325 | uint8_t pin;
326 | bool activeLow;
327 | bool stablePressed;
328 | bool lastRawPressed;
329 | bool pressedEvent;
330 | uint32_t lastChangeMs;
331 | uint16_t debounceMs;

332
333 | void begin(uint8_t buttonPin, uint16_t debounce, bool useActiveLow = true) {
334 | pin = buttonPin;
335 | activeLow = useActiveLow;
336 | stablePressed = false;
337 | lastRawPressed = false;

338 | pressedEvent = false;
339 | lastChangeMs = 0;
340 | debounceMs = debounce;

341
342 | if (pin != 255) {
343 | pinMode(pin, activeLow ? INPUT_PULLUP : INPUT);
344 | }
345 | }

346
347 | void update(uint32_t nowMs) {
348 | pressedEvent = false;
349 | if (pin == 255) {
350 | return;
351 | }

352
353 | bool rawPressed = activeLow ? (digitalRead(pin) == LOW) : (digitalRead(pin) == HIGH);
354 | if (rawPressed != lastRawPressed) {
355 | lastRawPressed = rawPressed;
356 | lastChangeMs = nowMs;
357 | }

358
359 | if ((nowMs - lastChangeMs) >= debounceMs && rawPressed != stablePressed) {
360 | stablePressed = rawPressed;
361 | if (stablePressed) {
362 | pressedEvent = true;
363 | }
364 | }
365 | }

366
367 | bool wasPressed() const {
368 | return pressedEvent;
369 | }
370 | };

371
372 | struct ExpanderButton {
373 | uint8_t bit;
374 | bool stablePressed;
375 | bool lastRawPressed;
376 | bool pressedEvent;
377 | uint32_t lastChangeMs;
378 | uint16_t debounceMs;

379
380 | void begin(uint8_t expanderBit, uint16_t debounce) {
381 | bit = expanderBit;
382 | stablePressed = false;
383 | lastRawPressed = false;
384 | pressedEvent = false;
385 | lastChangeMs = 0;
386 | debounceMs = debounce;
387 | }

388
389 | void update(uint32_t nowMs, uint16_t portState) {
390 | pressedEvent = false;
391 | if (bit >= 16) {
392 | return;
393 | }

394
395 | bool rawPressed = (portState & (1U << bit)) == 0;
396 | if (rawPressed != lastRawPressed) {
397 | lastRawPressed = rawPressed;
398 | lastChangeMs = nowMs;
399 | }

400
401 | if ((nowMs - lastChangeMs) >= debounceMs && rawPressed != stablePressed) {
402 | stablePressed = rawPressed;
403 | if (stablePressed) {
404 | pressedEvent = true;
405 | }
406 | }
407 | }

408
409 | bool wasPressed() const {
410 | return pressedEvent;
411 | }
412 | };

413
414 | struct Rect {
415 | int16_t x;
416 | int16_t y;
417 | int16_t w;
418 | int16_t h;

419
420 | bool contains(int16_t px, int16_t py) const {
421 | return px >= x && py >= y && px < x + w && py < y + h;
422 | }

423

424 | bool containsPadded(int16_t px, int16_t py, int16_t padX, int16_t padY) const {
425 | return px >= x - padX && py >= y - padY && px < x + w + padX && py < y + h + padY;
426 | }
427 | };

428
429 | struct TouchPoint {
430 | bool touched;
431 | uint16_t x;
432 | uint16_t y;
433 | };

434
435 | // ---------------------------------------------------------------------------
436 | // Globals
437 | // ---------------------------------------------------------------------------
438 | class CrowPanelRGBDisplay {
439 | public:
440 | CrowPanelRGBDisplay(uint8_t csPin, uint8_t dcPin, uint8_t rstPin)
441 | : cs(csPin), dc(dcPin), rst(rstPin) {}

442
443 | void begin() {
444 | (void)cs;
445 | (void)dc;
446 | (void)rst;

447
448 | esp_lcd_rgb_panel_config_t panelConfig = {};
449 | panelConfig.clk_src = LCD_CLK_SRC_DEFAULT;
450 | panelConfig.timings.pclk_hz = LCD_PIXEL_CLOCK_HZ;
451 | panelConfig.timings.h_res = PANEL_WIDTH;
452 | panelConfig.timings.v_res = PANEL_HEIGHT;
453 | panelConfig.timings.hsync_pulse_width = 4;
454 | panelConfig.timings.hsync_back_porch = 43;
455 | panelConfig.timings.hsync_front_porch = 8;
456 | panelConfig.timings.vsync_pulse_width = 4;
457 | panelConfig.timings.vsync_back_porch = 12;
458 | panelConfig.timings.vsync_front_porch = 8;
459 | panelConfig.timings.flags.hsync_idle_low = 0;
460 | panelConfig.timings.flags.vsync_idle_low = 0;
461 | panelConfig.timings.flags.de_idle_high = 0;
462 | panelConfig.timings.flags.pclk_active_neg = 1;
463 | panelConfig.timings.flags.pclk_idle_high = 0;
464 | panelConfig.data_width = 16;
465 | panelConfig.bits_per_pixel = 16;
466 | panelConfig.num_fbs = 1;
467 | panelConfig.bounce_buffer_size_px = PANEL_WIDTH * LCD_BOUNCE_BUFFER_LINES;
468 | panelConfig.dma_burst_size = 32;
469 | panelConfig.hsync_gpio_num = PIN_LCD_HSYNC;
470 | panelConfig.vsync_gpio_num = PIN_LCD_VSYNC;
471 | panelConfig.de_gpio_num = PIN_LCD_DE;
472 | panelConfig.pclk_gpio_num = PIN_LCD_PCLK;
473 | panelConfig.disp_gpio_num = -1;
474 | panelConfig.data_gpio_nums[0] = PIN_LCD_D0;
475 | panelConfig.data_gpio_nums[1] = PIN_LCD_D1;
476 | panelConfig.data_gpio_nums[2] = PIN_LCD_D2;
477 | panelConfig.data_gpio_nums[3] = PIN_LCD_D3;
478 | panelConfig.data_gpio_nums[4] = PIN_LCD_D4;
479 | panelConfig.data_gpio_nums[5] = PIN_LCD_D5;
480 | panelConfig.data_gpio_nums[6] = PIN_LCD_D6;
481 | panelConfig.data_gpio_nums[7] = PIN_LCD_D7;
482 | panelConfig.data_gpio_nums[8] = PIN_LCD_D8;
483 | panelConfig.data_gpio_nums[9] = PIN_LCD_D9;
484 | panelConfig.data_gpio_nums[10] = PIN_LCD_D10;
485 | panelConfig.data_gpio_nums[11] = PIN_LCD_D11;
486 | panelConfig.data_gpio_nums[12] = PIN_LCD_D12;
487 | panelConfig.data_gpio_nums[13] = PIN_LCD_D13;
488 | panelConfig.data_gpio_nums[14] = PIN_LCD_D14;
489 | panelConfig.data_gpio_nums[15] = PIN_LCD_D15;
490 | panelConfig.flags.fb_in_psram = 1;

491
492 | esp_err_t err = esp_lcd_new_rgb_panel(&panelConfig, &panelHandle);
493 | logPrintf("esp_lcd_new_rgb_panel: %d\n", err);
494 | if (err != ESP_OK) {
495 | panelHandle = nullptr;
496 | return;
497 | }

498
499 | err = esp_lcd_panel_reset(panelHandle);
500 | logPrintf("esp_lcd_panel_reset: %d\n", err);
501 | err = esp_lcd_panel_init(panelHandle);
502 | logPrintf("esp_lcd_panel_init: %d\n", err);

503
504 | lineBuffer = (uint16_t *)heap_caps_malloc(PANEL_WIDTH * sizeof(uint16_t), MALLOC_CAP_INTERNAL | MALLOC_CAP_8BIT);
505 | if (lineBuffer == nullptr) {
506 | lineBuffer = (uint16_t *)heap_caps_malloc(PANEL_WIDTH * sizeof(uint16_t), MALLOC_CAP_8BIT);
507 | }
508 | logPrintf("LCD line buffer: %s\n", lineBuffer == nullptr ? "FAILED" : "OK");
509 | }

510
511 | void setRotation(uint8_t rotation) {
512 | (void)rotation;
513 | screenWidth = PANEL_WIDTH;
514 | screenHeight = PANEL_HEIGHT;
515 | }

516
517 | void fillScreen(uint16_t color) {
518 | fillRect(0, 0, screenWidth, screenHeight, color);
519 | }

520
521 | void setTextSize(uint8_t size) {
522 | textSize = (size == 0) ? 1 : size;
523 | }

524
525 | void setTextColor(uint16_t color, uint16_t background) {
526 | textColor = color;
527 | textBackground = background;
528 | }

529
530 | void setFont(const GFXfont *font = nullptr) {
531 | gfxFont = font;
532 | }

533
534 | void setCursor(int16_t x, int16_t y) {
535 | cursorX = x;
536 | cursorY = y;
537 | }

538
539 | void print(const String &text) {
540 | print(text.c_str());
541 | }

542
543 | void print(const char *text) {
544 | if (text == nullptr) {
545 | return;
546 | }
547 | while (*text) {
548 | drawChar(*text++);
549 | }
550 | }

551
552 | void print(int value) {
553 | char buffer[16];
554 | snprintf(buffer, sizeof(buffer), "%d", value);
555 | print(buffer);
556 | }

557
558 | void print(unsigned int value) {
559 | char buffer[16];
560 | snprintf(buffer, sizeof(buffer), "%u", value);
561 | print(buffer);
562 | }

563
564 | void print(unsigned long value) {
565 | char buffer[20];
566 | snprintf(buffer, sizeof(buffer), "%lu", value);
567 | print(buffer);
568 | }

569
570 | void printf(const char *format, ...) {
571 | char buffer[80];
572 | va_list args;
573 | va_start(args, format);
574 | vsnprintf(buffer, sizeof(buffer), format, args);
575 | va_end(args);
576 | print(buffer);
577 | }

578
579 | int16_t width() const { return screenWidth; }
580 | int16_t height() const { return screenHeight; }

581
582 | void fillRect(int16_t x, int16_t y, int16_t w, int16_t h, uint16_t color) {
583 | if (w <= 0 || h <= 0 || x >= screenWidth || y >= screenHeight) {
584 | return;
585 | }
586 | if (x < 0) {
587 | w += x;
588 | x = 0;
589 | }
590 | if (y < 0) {
591 | h += y;
592 | y = 0;
593 | }
594 | if (x + w > screenWidth) {
595 | w = screenWidth - x;

596 | }
597 | if (y + h > screenHeight) {
598 | h = screenHeight - y;
599 | }
600 | if (w <= 0 || h <= 0) {
601 | return;
602 | }

603
604 | if (panelHandle == nullptr || lineBuffer == nullptr) {
605 | return;
606 | }

607
608 | for (int16_t col = 0; col < w; col++) {
609 | lineBuffer[col] = color;
610 | }

611
612 | for (int16_t row = 0; row < h; row++) {
613 | esp_lcd_panel_draw_bitmap(panelHandle, x, y + row, x + w, y + row + 1, lineBuffer);
614 | }
615 | }

616
617 | void drawRGB565Image(int16_t x, int16_t y, uint16_t w, uint16_t h, const uint16_t *pixels) {
618 | if (panelHandle == nullptr || lineBuffer == nullptr || pixels == nullptr) {
619 | return;
620 | }

621
622 | uint16_t drawWidth = w;
623 | uint16_t drawHeight = h;
624 | if (x < 0 || y < 0 || x >= screenWidth || y >= screenHeight) {
625 | return;
626 | }
627 | if (x + drawWidth > screenWidth) {
628 | drawWidth = screenWidth - x;
629 | }
630 | if (y + drawHeight > screenHeight) {
631 | drawHeight = screenHeight - y;
632 | }

633
634 | for (uint16_t row = 0; row < drawHeight; row++) {
635 | const uint32_t sourceOffset = (uint32_t)row * (uint32_t)w;
636 | for (uint16_t col = 0; col < drawWidth; col++) {
637 | lineBuffer[col] = pgm_read_word(&pixels[sourceOffset + col]);
638 | }
639 | esp_lcd_panel_draw_bitmap(panelHandle, x, y + row, x + drawWidth, y + row + 1, lineBuffer);
640 | }
641 | }

642
643 | void drawRGB565ImageScaled2x(int16_t x, int16_t y, uint16_t w, uint16_t h, const uint16_t *pixels) {
644 | if (panelHandle == nullptr || lineBuffer == nullptr || pixels == nullptr) {
645 | return;
646 | }

647
648 | uint16_t drawWidth = w * 2;
649 | uint16_t drawHeight = h * 2;
650 | if (x < 0 || y < 0 || x >= screenWidth || y >= screenHeight) {
651 | return;
652 | }
653 | if (x + drawWidth > screenWidth) {
654 | drawWidth = screenWidth - x;
655 | }
656 | if (y + drawHeight > screenHeight) {
657 | drawHeight = screenHeight - y;
658 | }

659
660 | for (uint16_t row = 0; row < drawHeight; row++) {
661 | const uint32_t sourceOffset = (uint32_t)(row / 2) * (uint32_t)w;
662 | for (uint16_t col = 0; col < drawWidth; col++) {
663 | lineBuffer[col] = pgm_read_word(&pixels[sourceOffset + (col / 2)]);
664 | }
665 | esp_lcd_panel_draw_bitmap(panelHandle, x, y + row, x + drawWidth, y + row + 1, lineBuffer);
666 | }
667 | }

668
669 | void drawRoundRect(int16_t x, int16_t y, int16_t w, int16_t h, int16_t radius, uint16_t color) {
670 | (void)radius;
671 | fillRect(x, y, w, 1, color);
672 | fillRect(x, y + h - 1, w, 1, color);
673 | fillRect(x, y, 1, h, color);
674 | fillRect(x + w - 1, y, 1, h, color);
675 | }

676
677 | void getTextBounds(const String &text, int16_t x, int16_t y, int16_t *x1, int16_t *y1, uint16_t *w, uint16_t *h) {
678 | if (gfxFont != nullptr) {
679 | getGfxTextBounds(text, x, y, x1, y1, w, h);
680 | return;
681 | }

682 | *x1 = 0;
683 | *y1 = 0;
684 | *w = text.length() * 6 * textSize;
685 | *h = 8 * textSize;
686 | }

687
688 | private:
689 | void writeCommand(uint8_t command) {
690 | (void)command;
691 | }

692
693 | void writeData(uint8_t data) {
694 | (void)data;
695 | }

696
697 | void writeData16(uint16_t data) {
698 | (void)data;
699 | }

700
701 | void setAddressWindow(uint16_t x0, uint16_t y0, uint16_t x1, uint16_t y1) {
702 | writeCommand(0x2A);
703 | writeData16(x0);
704 | writeData16(x1);
705 | writeCommand(0x2B);
706 | writeData16(y0);
707 | writeData16(y1);
708 | writeCommand(0x2C);
709 | }

710
711 | void drawPixel(int16_t x, int16_t y, uint16_t color) {
712 | if (x < 0 || y < 0 || x >= screenWidth || y >= screenHeight) {
713 | return;
714 | }
715 | fillRect(x, y, 1, 1, color);
716 | }

717
718 | void getGfxTextBounds(const String &text, int16_t x, int16_t y, int16_t *x1, int16_t *y1, uint16_t *w, uint16_t *h) {
719 | int16_t minX = 32767;
720 | int16_t minY = 32767;
721 | int16_t maxX = -32768;
722 | int16_t maxY = -32768;
723 | int16_t cursor = x;
724 | uint16_t first = pgm_read_word(&gfxFont->first);
725 | uint16_t last = pgm_read_word(&gfxFont->last);
726 | const GFXglyph *glyphs = (const GFXglyph *)pgm_read_ptr(&gfxFont->glyph);

727
728 | for (uint16_t i = 0; i < text.length(); i++) {
729 | char c = text.charAt(i);
730 | if (c < first || c > last) {
731 | continue;
732 | }
733 | GFXglyph glyph;
734 | memcpy_P(&glyph, &glyphs[c - first], sizeof(GFXglyph));
735 | if (glyph.width > 0 && glyph.height > 0) {
736 | int16_t gx1 = cursor + (glyph.xOffset * textSize);
737 | int16_t gy1 = y + (glyph.yOffset * textSize);
738 | int16_t gx2 = gx1 + ((int16_t)glyph.width * textSize) - 1;
739 | int16_t gy2 = gy1 + ((int16_t)glyph.height * textSize) - 1;
740 | if (gx1 < minX) minX = gx1;
741 | if (gy1 < minY) minY = gy1;
742 | if (gx2 > maxX) maxX = gx2;
743 | if (gy2 > maxY) maxY = gy2;
744 | }
745 | cursor += (int16_t)glyph.xAdvance * textSize;
746 | }

747
748 | if (maxX < minX || maxY < minY) {
749 | *x1 = x;
750 | *y1 = y;
751 | *w = 0;
752 | *h = 0;
753 | return;
754 | }

755
756 | *x1 = minX;
757 | *y1 = minY;
758 | *w = maxX - minX + 1;
759 | *h = maxY - minY + 1;
760 | }

761
762 | const char *glyphRow(char c, uint8_t row) const {
763 | if (c >= ’a’ && c <= ’z’) {
764 | c -= 32;
765 | }
766 | static const char blank[7][6] = {"00000","00000","00000","00000","00000","00000","00000"};
767 | static const char unknown[7][6] = {"11111","10001","00010","00100","00100","00000","00100"};

768 | #define GLYPH(ch, a,b,c,d,e,f,g) case ch: { static const char p[7][6] = {a,b,c,d,e,f,g}; return p[row]; }
769 | switch (c) {
770 | GLYPH(’ ’, "00000","00000","00000","00000","00000","00000","00000")
771 | GLYPH(’0’, "01110","10001","10011","10101","11001","10001","01110")
772 | GLYPH(’1’, "00100","01100","00100","00100","00100","00100","01110")
773 | GLYPH(’2’, "01110","10001","00001","00010","00100","01000","11111")
774 | GLYPH(’3’, "11110","00001","00001","01110","00001","00001","11110")
775 | GLYPH(’4’, "00010","00110","01010","10010","11111","00010","00010")
776 | GLYPH(’5’, "11111","10000","10000","11110","00001","00001","11110")
777 | GLYPH(’6’, "01110","10000","10000","11110","10001","10001","01110")
778 | GLYPH(’7’, "11111","00001","00010","00100","01000","01000","01000")
779 | GLYPH(’8’, "01110","10001","10001","01110","10001","10001","01110")
780 | GLYPH(’9’, "01110","10001","10001","01111","00001","00001","01110")
781 | GLYPH(’A’, "01110","10001","10001","11111","10001","10001","10001")
782 | GLYPH(’B’, "11110","10001","10001","11110","10001","10001","11110")
783 | GLYPH(’C’, "01111","10000","10000","10000","10000","10000","01111")
784 | GLYPH(’D’, "11110","10001","10001","10001","10001","10001","11110")
785 | GLYPH(’E’, "11111","10000","10000","11110","10000","10000","11111")
786 | GLYPH(’F’, "11111","10000","10000","11110","10000","10000","10000")
787 | GLYPH(’G’, "01111","10000","10000","10011","10001","10001","01111")
788 | GLYPH(’H’, "10001","10001","10001","11111","10001","10001","10001")
789 | GLYPH(’I’, "01110","00100","00100","00100","00100","00100","01110")
790 | GLYPH(’J’, "00111","00010","00010","00010","00010","10010","01100")
791 | GLYPH(’K’, "10001","10010","10100","11000","10100","10010","10001")
792 | GLYPH(’L’, "10000","10000","10000","10000","10000","10000","11111")
793 | GLYPH(’M’, "10001","11011","10101","10101","10001","10001","10001")
794 | GLYPH(’N’, "10001","11001","10101","10011","10001","10001","10001")
795 | GLYPH(’O’, "01110","10001","10001","10001","10001","10001","01110")
796 | GLYPH(’P’, "11110","10001","10001","11110","10000","10000","10000")
797 | GLYPH(’Q’, "01110","10001","10001","10001","10101","10010","01101")
798 | GLYPH(’R’, "11110","10001","10001","11110","10100","10010","10001")
799 | GLYPH(’S’, "01111","10000","10000","01110","00001","00001","11110")
800 | GLYPH(’T’, "11111","00100","00100","00100","00100","00100","00100")
801 | GLYPH(’U’, "10001","10001","10001","10001","10001","10001","01110")
802 | GLYPH(’V’, "10001","10001","10001","10001","10001","01010","00100")
803 | GLYPH(’W’, "10001","10001","10001","10101","10101","10101","01010")
804 | GLYPH(’X’, "10001","10001","01010","00100","01010","10001","10001")
805 | GLYPH(’Y’, "10001","10001","01010","00100","00100","00100","00100")
806 | GLYPH(’Z’, "11111","00001","00010","00100","01000","10000","11111")
807 | GLYPH(’:’, "00000","00100","00100","00000","00100","00100","00000")
808 | GLYPH(’.’, "00000","00000","00000","00000","00000","01100","01100")
809 | GLYPH(’-’, "00000","00000","00000","11111","00000","00000","00000")
810 | GLYPH(’/’, "00001","00010","00010","00100","01000","01000","10000")
811 | GLYPH(’+’, "00000","00100","00100","11111","00100","00100","00000")
812 | GLYPH(’%’, "11001","11010","00010","00100","01000","01011","10011")
813 | default:
814 | return (c == ’\0’) ? blank[row] : unknown[row];
815 | }
816 | #undef GLYPH
817 | }

818
819 | void drawChar(char c) {
820 | if (c == ’\n’) {
821 | cursorX = 0;
822 | cursorY += gfxFont == nullptr ? (8 * textSize) : (pgm_read_word(&gfxFont->yAdvance) * textSize);
823 | return;
824 | }

825
826 | if (gfxFont != nullptr) {
827 | drawGfxChar(c);
828 | return;
829 | }

830
831 | for (uint8_t row = 0; row < 7; row++) {
832 | const char *bits = glyphRow(c, row);
833 | for (uint8_t col = 0; col < 5; col++) {
834 | uint16_t color = (bits[col] == ’1’) ? textColor : textBackground;
835 | fillRect(cursorX + col * textSize, cursorY + row * textSize, textSize, textSize, color);
836 | }
837 | }
838 | fillRect(cursorX + 5 * textSize, cursorY, textSize, 7 * textSize, textBackground);
839 | cursorX += 6 * textSize;
840 | }

841
842 | void drawGfxChar(char c) {
843 | uint16_t first = pgm_read_word(&gfxFont->first);
844 | uint16_t last = pgm_read_word(&gfxFont->last);
845 | if (c < first || c > last) {
846 | return;
847 | }

848
849 | const GFXglyph *glyphs = (const GFXglyph *)pgm_read_ptr(&gfxFont->glyph);
850 | const uint8_t *bitmap = (const uint8_t *)pgm_read_ptr(&gfxFont->bitmap);
851 | GFXglyph glyph;
852 | memcpy_P(&glyph, &glyphs[c - first], sizeof(GFXglyph));

853

854 | uint16_t bitIndex = 0;
855 | uint16_t bitmapOffset = glyph.bitmapOffset;
856 | uint8_t bits = 0;
857 | for (uint8_t yy = 0; yy < glyph.height; yy++) {
858 | for (uint8_t xx = 0; xx < glyph.width; xx++) {
859 | if ((bitIndex & 7) == 0) {
860 | bits = pgm_read_byte(&bitmap[bitmapOffset++]);
861 | }
862 | if (bits & 0x80) {
863 | fillRect(cursorX + (glyph.xOffset + xx) * textSize, cursorY + (glyph.yOffset + yy) * textSize,
864 | textSize, textSize, textColor);
865 | }
866 | bits <<= 1;
867 | bitIndex++;
868 | }
869 | }
870 | cursorX += (int16_t)glyph.xAdvance * textSize;
871 | }

872
873 | uint8_t cs;
874 | uint8_t dc;
875 | uint8_t rst;
876 | int16_t screenWidth = PANEL_WIDTH;
877 | int16_t screenHeight = PANEL_HEIGHT;
878 | int16_t cursorX = 0;
879 | int16_t cursorY = 0;
880 | uint16_t textColor = ILI9341_WHITE;
881 | uint16_t textBackground = ILI9341_BLACK;
882 | uint8_t textSize = 1;
883 | const GFXfont *gfxFont = nullptr;
884 | esp_lcd_panel_handle_t panelHandle = nullptr;
885 | uint16_t *lineBuffer = nullptr;
886 | };

887
888 | CrowPanelRGBDisplay tft(255, 255, 255);
889 | Preferences prefs;

890
891 | DebouncedButton btnPlayerA;
892 | DebouncedButton btnPlayerB;
893 | DebouncedButton btnScoreAPlus;
894 | DebouncedButton btnScoreAMinus;
895 | DebouncedButton btnScoreBPlus;
896 | DebouncedButton btnScoreBMinus;
897 | DebouncedButton btnSelect;
898 | DebouncedButton btnUp;
899 | DebouncedButton btnDown;
900 | ExpanderButton expanderBtnPlayerA;
901 | ExpanderButton expanderBtnPlayerB;
902 | ExpanderButton expanderBtnPlayPause;

903
904 | int playerA_score = 0;
905 | int playerB_score = 0;
906 | int match_target = 9;
907 | uint32_t playerA_time_remaining = DEFAULT_INITIAL_TIME_SECONDS * 1000UL;
908 | uint32_t playerB_time_remaining = DEFAULT_INITIAL_TIME_SECONDS * 1000UL;
909 | uint32_t match_elapsed_seconds = 0;
910 | Player active_player = PLAYER_NONE;
911 | bool clock_running = false;
912 | bool crawford_used = false;
913 | bool crawford_active = false;
914 | bool post_crawford = false;
915 | bool cube_enabled = true;
916 | uint16_t game_number = 0;

917
918 | uint32_t initial_time_seconds = DEFAULT_INITIAL_TIME_SECONDS;
919 | uint8_t delay_seconds = DEFAULT_DELAY_SECONDS;
920 | uint8_t increment_seconds = DEFAULT_INCREMENT_SECONDS;
921 | uint8_t brightness = DEFAULT_BRIGHTNESS;
922 | TimingMode timingMode = SIMPLE_DELAY;
923 | TimerScope timerScope = TIMER_BY_MATCH;
924 | DisplayTheme displayTheme = THEME_NIGHT;
925 | ScoreDisplayMode scoreDisplayMode = SCORE_STANDARD;
926 | String playerA_name = "PLAYER A";
927 | String playerB_name = "PLAYER B";
928 | uint16_t playerA_color = PLAYER_COLOR_BLUE;
929 | uint16_t playerB_color = PLAYER_COLOR_RED;
930 | String matchLog[MATCH_LOG_MAX_ENTRIES];
931 | uint8_t matchLogCount = 0;

932
933 | DeviceMode mode = MODE_MENU;
934 | MenuItem currentMenuItem = MENU_MATCH_TARGET;
935 | Player timeoutPlayer = PLAYER_NONE;
936 | Player matchWinner = PLAYER_NONE;
937 | Player editingNameFor = PLAYER_NONE;
938 | String editingName;
939 | uint16_t editingPlayerColor = PLAYER_COLOR_BLUE;

940
941 | bool pending_crawford_next_game = false;
942 | bool game_in_progress = false;
943 | bool settingsDirty = false;
944 | bool displayDirty = true;
945 | bool displayModeKnown = false;
946 | DeviceMode lastDrawMode = MODE_MENU;
947 | uint32_t settingsDirtyMs = 0;
948 | uint32_t lastTickMs = 0;
949 | uint32_t turnStartMs = 0;
950 | uint32_t pausedTurnElapsedMs = 0;
951 | uint32_t lastDisplayMs = 0;
952 | uint32_t lastActivityMs = 0;
953 | uint32_t lastLowTimeBeepMs = 0;
954 | uint8_t gt911Address = 0;
955 | bool touchWasDown = false;
956 | uint16_t touchStartX = 0;
957 | uint16_t touchStartY = 0;
958 | uint16_t touchLastX = 0;
959 | uint16_t touchLastY = 0;
960 | uint16_t touchMinY = 0;
961 | uint16_t touchMaxY = 0;
962 | uint32_t touchStartMs = 0;
963 | uint32_t touchLastSeenMs = 0;
964 | uint32_t touchLastHandledMs = 0;
965 | uint8_t pca9557Address = 0;
966 | uint8_t pcf8575Address = 0;
967 | bool max17048Found = false;
968 | bool ds3231Found = false;
969 | bool lastTouchSeen = false;
970 | float lastChargeCheckVoltage = 0.0f;
971 | float lastChargeCheckPercent = 0.0f;
972 | bool chargeTrendRising = false;
973 | uint32_t lastChargeCheckMs = 0;
974 | uint32_t chargeIndicatorUntilMs = 0;
975 | String cachedRtcStatus = "DATE UNSET";
976 | uint32_t lastRtcStatusMs = 0;
977 | uint16_t editingRtcYear = 2026;
978 | uint8_t editingRtcMonth = 1;
979 | uint8_t editingRtcDay = 1;
980 | uint8_t editingRtcHour = 12;
981 | uint8_t editingRtcMinute = 0;

982
983 | const int MATCH_TARGETS[] = {1, 3, 5, 7, 9, 11, 13, 15, 17, 19, 21};
984 | const uint8_t MATCH_TARGET_COUNT = sizeof(MATCH_TARGETS) / sizeof(MATCH_TARGETS[0]);

985
986 | const Rect REGION_STATUS = {0, 0, 800, 34};
987 | const Rect REGION_HEADER_A = {12, 42, 228, 32};
988 | const Rect REGION_TIMER_A = {12, 88, 228, 108};
989 | const Rect REGION_SCORE_A = {12, 210, 228, 246};
990 | const Rect REGION_PLAY_PAUSE = {255, 42, 290, 56};
991 | const Rect REGION_END_GAME = {255, 113, 140, 56};
992 | const Rect REGION_END_MATCH = {405, 113, 140, 56};
993 | const Rect REGION_MATCH_TARGET = {255, 184, 290, 211};
994 | const Rect REGION_LOG = {255, 410, 140, 46};
995 | const Rect REGION_SETTINGS = {405, 410, 140, 46};
996 | const Rect REGION_HEADER_B = {560, 42, 228, 32};
997 | const Rect REGION_TIMER_B = {560, 88, 228, 108};
998 | const Rect REGION_SCORE_B = {560, 210, 228, 246};
999 | const Rect HIT_PLAY_PAUSE = {245, 36, 310, 70};
1000 | const Rect HIT_END_GAME = {245, 106, 150, 70};
1001 | const Rect HIT_END_MATCH = {405, 106, 150, 70};
1002 | const Rect CONFIRM_NO = {172, 306, 190, 62};
1003 | const Rect CONFIRM_YES = {438, 306, 190, 62};

1004
1005 | const Rect SETTINGS_MATCH_MINUS = {372, 86, 96, 48};
1006 | const Rect SETTINGS_MATCH_PLUS = {672, 86, 96, 48};
1007 | const Rect SETTINGS_TIME_MINUS = {372, 166, 96, 48};
1008 | const Rect SETTINGS_TIME_PLUS = {672, 166, 96, 48};
1009 | const Rect SETTINGS_DELAY_MINUS = {372, 246, 96, 48};
1010 | const Rect SETTINGS_DELAY_PLUS = {672, 246, 96, 48};
1011 | const Rect SETTINGS_MATCH_ROW_MINUS = {52, 82, 348, 58};
1012 | const Rect SETTINGS_MATCH_ROW_PLUS = {400, 82, 348, 58};
1013 | const Rect SETTINGS_TIME_ROW_MINUS = {52, 162, 348, 58};
1014 | const Rect SETTINGS_TIME_ROW_PLUS = {400, 162, 348, 58};
1015 | const Rect SETTINGS_DELAY_ROW_MINUS = {52, 242, 348, 58};
1016 | const Rect SETTINGS_DELAY_ROW_PLUS = {400, 242, 348, 58};
1017 | const Rect SETTINGS_SCOPE_GAME = {255, 306, 120, 36};
1018 | const Rect SETTINGS_SCOPE_MATCH = {392, 306, 120, 36};
1019 | const Rect SETTINGS_MODE_SIMPLE = {52, 352, 210, 38};
1020 | const Rect SETTINGS_MODE_BRONSTEIN = {295, 352, 210, 38};
1021 | const Rect SETTINGS_MODE_FISCHER = {538, 352, 210, 38};
1022 | const Rect SETTINGS_APPEARANCE = {52, 410, 170, 44};
1023 | const Rect SETTINGS_CLOCK = {240, 410, 130, 44};
1024 | const Rect SETTINGS_START = {388, 410, 170, 44};
1025 | const Rect SETTINGS_END = {576, 410, 170, 44};

1026 | const Rect SETTINGS_BACK = {24, 24, 108, 44};
1027 | const Rect LOG_BACK = {24, 24, 108, 44};
1028 | const Rect LOG_CLEAR = {650, 24, 108, 44};
1029 | const Rect CLOCK_BACK = {24, 24, 108, 44};
1030 | const Rect APPEARANCE_BACK = {24, 24, 108, 44};
1031 | const Rect APPEARANCE_NIGHT = {170, 132, 220, 64};
1032 | const Rect APPEARANCE_DAY = {410, 132, 220, 64};
1033 | const Rect APPEARANCE_SCORE = {170, 286, 220, 64};
1034 | const Rect APPEARANCE_POINTS = {410, 286, 220, 64};
1035 | const Rect CLOCK_SAVE = {560, 400, 168, 48};
1036 | const Rect CLOCK_YEAR_MINUS = {372, 84, 96, 44};
1037 | const Rect CLOCK_YEAR_PLUS = {672, 84, 96, 44};
1038 | const Rect CLOCK_MONTH_MINUS = {372, 142, 96, 44};
1039 | const Rect CLOCK_MONTH_PLUS = {672, 142, 96, 44};
1040 | const Rect CLOCK_DAY_MINUS = {372, 200, 96, 44};
1041 | const Rect CLOCK_DAY_PLUS = {672, 200, 96, 44};
1042 | const Rect CLOCK_HOUR_MINUS = {372, 258, 96, 44};
1043 | const Rect CLOCK_HOUR_PLUS = {672, 258, 96, 44};
1044 | const Rect CLOCK_MINUTE_MINUS = {372, 316, 96, 44};
1045 | const Rect CLOCK_MINUTE_PLUS = {672, 316, 96, 44};

1046
1047 | // ---------------------------------------------------------------------------
1048 | // Forward declarations requested by the firmware structure.
1049 | // ---------------------------------------------------------------------------
1050 | void drawDisplay();
1051 | void drawTimerPanels();
1052 | void drawTimerPanel(Player player, const Rect &region);
1053 | void drawSplashImage();
1054 | void fillTriangleRows(int16_t x0, int16_t y0, int16_t x1, int16_t y1, int16_t x2, int16_t y2, uint16_t color);
1055 | void fillCircleRows(int16_t cx, int16_t cy, int16_t radius, uint16_t color);
1056 | void drawCenteredInRect(const String &text, const Rect &region, uint8_t textSize, uint16_t color, uint16_t background);
1057 | void drawScoreInRect(int score, const Rect &region, uint16_t color, uint16_t background);
1058 | void drawMatchTargetInRect(int target, const Rect &region, uint16_t color, uint16_t background);
1059 | void drawGfxTextScaledInRect(const GFXfont *font, const String &text, const Rect &region, uint16_t color, uint8_t scaleNum, uint8_t
| scaleDen);
1060 | void getGfxTextBoundsScaled(const GFXfont *font, const String &text, uint8_t scaleNum, uint8_t scaleDen, int16_t *x1, int16_t *y1,
| uint16_t *w, uint16_t *h);
1061 | void drawGfxTextScaled(const GFXfont *font, const String &text, int16_t x, int16_t y, uint16_t color, uint8_t scaleNum, uint8_t scaleDen)
| ;
1062 | void drawMatchWinnerBanner();
1063 | void drawTimeoutBanner();
1064 | void drawNameEditor();
1065 | void drawMatchLog();
1066 | void drawClockSettings();
1067 | void drawAppearanceSettings();
1068 | void drawEndMatchConfirm();
1069 | void openClockSettings();
1070 | void handleClockSettingsTap(uint16_t x, uint16_t y);
1071 | void handleAppearanceSettingsTap(uint16_t x, uint16_t y);
1072 | void handleEndMatchConfirmTap(uint16_t x, uint16_t y);
1073 | void adjustRtcField(uint8_t field, int delta);
1074 | void openNameEditor(Player player);
1075 | void handleNameEditorTap(uint16_t x, uint16_t y);
1076 | uint16_t colorForPlayer(Player player);
1077 | uint16_t textColorForPlayerColor(uint16_t color);
1078 | uint16_t playerColorOption(uint8_t index);
1079 | uint8_t playerColorOptionCount();
1080 | void savePlayerNames();
1081 | void recordMatchLog();
1082 | void clearMatchLog();
1083 | String matchLogDate();
1084 | String matchLogPart(const String &entry, uint8_t part);
1085 | void handleButtons();
1086 | void handleTouch();
1087 | void handleTouchTap(uint16_t x, uint16_t y);
1088 | void handleTouchSwipe(uint16_t startX, uint16_t startY, uint16_t endX, uint16_t endY);
1089 | void updateClock();
1090 | void adjustScore(Player player, int delta);
1091 | void checkMatchState();
1092 | void startNewGame();
1093 | void endCurrentGame();
1094 | void markCrawfordUsed();
1095 | void forceEndMatch();
1096 | void resetMatch();
1097 | void enterMenu();
1098 | void handleMenu();

1099
1100 | // Helper declarations.
1101 | void loadSettings();
1102 | void saveSettingsIfNeeded();
1103 | void markSettingsDirty();
1104 | void markDisplayDirty();
1105 | void setBrightness(uint8_t duty);
1106 | void wakeActivity();
1107 | void maybeSleep();
1108 | void beep(uint16_t frequency, uint16_t durationMs);

1109 | void playButtonBeep();
1110 | void playTimeoutBeep();
1111 | void playMatchOverBeep();
1112 | void pauseClock();
1113 | void resumeClock();
1114 | void togglePlayPause();
1115 | void switchClockTo(Player nextPlayer);
1116 | void addIncrementTo(Player player);
1117 | bool applyTurnElapsed(Player player, uint32_t nowMs);
1118 | uint32_t visibleReserveMs(Player player, uint32_t nowMs);
1119 | uint32_t *reserveFor(Player player);
1120 | uint32_t matchClockSeconds();
1121 | uint32_t startingClockMs();
1122 | String formatTimeMs(uint32_t milliseconds);
1123 | String timingModeLabel();
1124 | String playPauseLabel();
1125 | void drawCentered(const String &text, int16_t y, uint8_t textSize, uint16_t color);
1126 | void drawPlayerPanel(Player player, int16_t x, int16_t y, int16_t w, int16_t h);
1127 | void drawStatusBar();
1128 | bool dayThemeEnabled();
1129 | uint16_t uiBackgroundColor();
1130 | uint16_t uiPanelColor();
1131 | uint16_t uiTextColor();
1132 | uint16_t uiMutedColor();
1133 | void drawChargeBolt(int16_t x, int16_t y, uint16_t color, uint16_t background);
1134 | void drawStartupTest();
1135 | void initCrowPanelExpander();
1136 | void initButtonExpander();
1137 | void initFuelGauge();
1138 | void initRtcClock();
1139 | bool pca9557Write(uint8_t address, uint8_t reg, uint8_t value);
1140 | uint8_t pca9557Read(uint8_t address, uint8_t reg);
1141 | bool pcf8575Write(uint8_t address, uint16_t value);
1142 | uint16_t pcf8575Read(uint8_t address);
1143 | bool max17048Read16(uint8_t reg, uint16_t *value);
1144 | bool max17048Write16(uint8_t reg, uint16_t value);
1145 | bool max17048QuickStart();
1146 | float max17048CellVoltage();
1147 | float max17048StateOfCharge();
1148 | bool ds3231ReadTime(uint8_t *second, uint8_t *minute, uint8_t *hour, uint8_t *day, uint8_t *month, uint16_t *year);
1149 | bool ds3231SetTime(uint8_t second, uint8_t minute, uint8_t hour, uint8_t day, uint8_t month, uint16_t year);
1150 | bool rtcDateLooksSet(uint8_t day, uint8_t month, uint16_t year);
1151 | uint8_t daysInMonth(uint8_t month, uint16_t year);
1152 | uint8_t bcdToDec(uint8_t value);
1153 | uint8_t decToBcd(uint8_t value);
1154 | String rtcStatusText();
1155 | bool updateRtcStatusCache(bool force);
1156 | void scanI2C(const char *label);
1157 | void resetTouchController(uint8_t outputValue, uint8_t configValue);
1158 | void initTouch();
1159 | TouchPoint readTouch();
1160 | bool gt911Read(uint16_t reg, uint8_t *data, uint8_t len);
1161 | bool gt911Write(uint16_t reg, uint8_t value);
1162 | String formatTime(uint32_t seconds);
1163 | String matchStateLabel();
1164 | int batteryPercent();
1165 | bool chargingIndicatorOn();
1166 | void changeMenuValue(int delta);
1167 | void nextMenuItem();
1168 | void previousMenuItem();
1169 | uint8_t findCurrentTargetIndex();

1170
1171 | // ---------------------------------------------------------------------------
1172 | // Arduino entry points
1173 | // ---------------------------------------------------------------------------
1174 | void setup() {
1175 | Serial.begin(115200);
1176 | Serial0.begin(115200);
1177 | delay(200);
1178 | logLine("");
1179 | logLine("Backgammon Match Clock booting");
1180 | logPrintf("Firmware: %s\n", FIRMWARE_VERSION);
1181 | logPrintf("PSRAM found: %s\n", psramFound() ? "yes" : "no");
1182 | logPrintf("Free PSRAM: %u bytes\n", ESP.getFreePsram());
1183 | logPrintf("Total PSRAM: %u bytes\n", ESP.getPsramSize());
1184 | if (!psramFound() || ESP.getPsramSize() < 800000) {
1185 | logLine("ERROR: PSRAM is not enabled. Set Tools > PSRAM to OPI PSRAM and upload again.");
1186 | }
1187 | logLine("Buttons are optional for startup; the menu should draw with no buttons connected.");
1188 | logPrintf("DIS07050H RGB panel: %ux%u, BL=%u, PCLK=%u HSYNC=%u VSYNC=%u DE=%u\n",
1189 | PANEL_WIDTH, PANEL_HEIGHT, PIN_TFT_BACKLIGHT, PIN_LCD_PCLK,
1190 | PIN_LCD_HSYNC, PIN_LCD_VSYNC, PIN_LCD_DE);

1191
1192 | btnPlayerA.begin(PIN_PLAYER_A_BUTTON, PLAYER_BUTTON_DEBOUNCE_MS);
1193 | btnPlayerB.begin(PIN_PLAYER_B_BUTTON, PLAYER_BUTTON_DEBOUNCE_MS);
1194 | btnScoreAPlus.begin(PIN_SCORE_A_PLUS, SMALL_BUTTON_DEBOUNCE_MS);

1195 | btnScoreAMinus.begin(PIN_SCORE_A_MINUS, SMALL_BUTTON_DEBOUNCE_MS);
1196 | btnScoreBPlus.begin(PIN_SCORE_B_PLUS, SMALL_BUTTON_DEBOUNCE_MS);
1197 | btnScoreBMinus.begin(PIN_SCORE_B_MINUS, SMALL_BUTTON_DEBOUNCE_MS);
1198 | btnSelect.begin(PIN_MENU_SELECT, SMALL_BUTTON_DEBOUNCE_MS);
1199 | btnUp.begin(PIN_MENU_UP, SMALL_BUTTON_DEBOUNCE_MS);
1200 | btnDown.begin(PIN_MENU_DOWN, SMALL_BUTTON_DEBOUNCE_MS);
1201 | expanderBtnPlayerA.begin(PCF8575_PLAYER_A_PIN, PLAYER_BUTTON_DEBOUNCE_MS);
1202 | expanderBtnPlayerB.begin(PCF8575_PLAYER_B_PIN, PLAYER_BUTTON_DEBOUNCE_MS);
1203 | expanderBtnPlayPause.begin(PCF8575_PLAY_PAUSE_PIN, PLAYER_BUTTON_DEBOUNCE_MS);

1204
1205 | if (PIN_BUZZER != 255) {
1206 | pinMode(PIN_BUZZER, OUTPUT);
1207 | digitalWrite(PIN_BUZZER, LOW);
1208 | }
1209 | if (PIN_CHARGE_DETECT != 255) {
1210 | pinMode(PIN_CHARGE_DETECT, INPUT_PULLUP);
1211 | }

1212
1213 | pinMode(PIN_TFT_BACKLIGHT, OUTPUT);
1214 | setBrightness(255);

1215
1216 analogReadResolution(12);

1217
1218 | initCrowPanelExpander();
1219 | initButtonExpander();
1220 | initFuelGauge();
1221 | initRtcClock();
1222 | initTouch();
1223 | tft.begin();
1224 | tft.setRotation(1);
1225 | drawStartupTest();

1226
1227 | loadSettings();
1228 | setBrightness(brightness);
1229 | resetMatch();
1230 | mode = MODE_MATCH;
1231 | markDisplayDirty();

1232
1233 | lastTickMs = millis();
1234 | lastActivityMs = lastTickMs;
1235 | updateRtcStatusCache(true);
1236 | drawDisplay();
1237 | displayDirty = false;
1238 | lastDisplayMs = lastTickMs;
1239 | }

1240
1241 | void loop() {
1242 | handleTouch();
1243 | handleButtons();

1244
1245 | if (mode == MODE_MATCH) {
1246 | updateClock();
1247 | }

1248
1249 | saveSettingsIfNeeded();
1250 | maybeSleep();

1251
1252 | uint32_t nowMs = millis();
1253 | if (!displayDirty && nowMs - lastRtcStatusMs >= 1000UL) {
1254 | bool rtcChanged = updateRtcStatusCache(false);
1255 | if (rtcChanged && (mode == MODE_MATCH || mode == MODE_MATCH_OVER || mode == MODE_TIMEOUT)) {
1256 | drawStatusBar();
1257 | }
1258 | }

1259
1260 | bool timeDisplayDue = (clock_running && nowMs - lastDisplayMs >= DISPLAY_REFRESH_MS);
1261 | if (displayDirty) {
1262 | drawDisplay();
1263 | lastDisplayMs = nowMs;
1264 | displayDirty = false;
1265 | } else if (timeDisplayDue) {
1266 | drawTimerPanels();
1267 | lastDisplayMs = nowMs;
1268 | }
1269 | }

1270
1271 | // ---------------------------------------------------------------------------
1272 | // Button handling
1273 | // ---------------------------------------------------------------------------
1274 | void handleButtons() {
1275 | uint32_t nowMs = millis();

1276
1277 | btnPlayerA.update(nowMs);
1278 | btnPlayerB.update(nowMs);
1279 | btnScoreAPlus.update(nowMs);
1280 | btnScoreAMinus.update(nowMs);

1281 | btnScoreBPlus.update(nowMs);
1282 | btnScoreBMinus.update(nowMs);
1283 | btnSelect.update(nowMs);
1284 | btnUp.update(nowMs);
1285 | btnDown.update(nowMs);

1286
1287 | uint16_t expanderState = (pcf8575Address == 0) ? 0xFFFF : pcf8575Read(pcf8575Address);
1288 | expanderBtnPlayerA.update(nowMs, expanderState);
1289 | expanderBtnPlayerB.update(nowMs, expanderState);
1290 | expanderBtnPlayPause.update(nowMs, expanderState);

1291
1292 | bool gpioPlayerAPressed = btnPlayerA.wasPressed();
1293 | bool gpioPlayerBPressed = btnPlayerB.wasPressed();
1294 | bool expanderPlayerAPressed = expanderBtnPlayerA.wasPressed();
1295 | bool expanderPlayerBPressed = expanderBtnPlayerB.wasPressed();
1296 | bool expanderPlayPausePressed = expanderBtnPlayPause.wasPressed();

1297
1298 | if (expanderPlayPausePressed) {
1299 | logPrintf("PCF8575 P00 Play/Pause pressed: mode=%u running=%s game=%s\n",
1300 | (unsigned int)mode,
1301 | clock_running ? "yes" : "no",
1302 | game_in_progress ? "yes" : "no");
1303 | }

1304
1305 | bool anyPress = gpioPlayerAPressed || gpioPlayerBPressed ||
1306 | expanderPlayerAPressed || expanderPlayerBPressed ||
1307 | expanderPlayPausePressed ||
1308 | btnScoreAPlus.wasPressed() || btnScoreAMinus.wasPressed() ||
1309 | btnScoreBPlus.wasPressed() || btnScoreBMinus.wasPressed() ||
1310 | btnSelect.wasPressed() || btnUp.wasPressed() || btnDown.wasPressed();

1311
1312 | if (anyPress) {
1313 | wakeActivity();
1314 | playButtonBeep();
1315 | }

1316
1317 | if (mode == MODE_MENU) {
1318 | handleMenu();
1319 | return;
1320 | }

1321
1322 | if (mode == MODE_NAME_EDIT) {
1323 | if (btnSelect.wasPressed()) {
1324 | mode = MODE_MATCH;
1325 | editingNameFor = PLAYER_NONE;
1326 | markDisplayDirty();
1327 | }
1328 | return;
1329 | }

1330
1331 | if (mode == MODE_LOG) {
1332 | if (btnSelect.wasPressed()) {
1333 | mode = MODE_MATCH;
1334 | markDisplayDirty();
1335 | }
1336 | return;
1337 | }

1338
1339 | if (mode == MODE_APPEARANCE) {
1340 | if (btnSelect.wasPressed()) {
1341 | mode = MODE_MENU;
1342 | markDisplayDirty();
1343 | }
1344 | return;
1345 | }

1346
1347 | if (mode == MODE_CONFIRM_END_MATCH) {
1348 | if (btnSelect.wasPressed()) {
1349 | mode = MODE_MATCH;
1350 | markDisplayDirty();
1351 | }
1352 | return;
1353 | }

1354
1355 | // The menu/select button pauses or resumes menu access during a match.
1356 | if (btnSelect.wasPressed()) {
1357 | enterMenu();
1358 | return;
1359 | }

1360
1361 | if (mode == MODE_MATCH) {
1362 | if (expanderPlayPausePressed) {
1363 | togglePlayPause();
1364 | return;
1365 | }

1366

1367 | if (gpioPlayerAPressed) {
1368 | if (clock_running && active_player == PLAYER_A) {
1369 | switchClockTo(PLAYER_B);
1370 | } else {
1371 | switchClockTo(PLAYER_A);
1372 | }
1373 | }
1374 | if (gpioPlayerBPressed) {
1375 | switchClockTo(PLAYER_A);
1376 | }
1377 | if (expanderPlayerAPressed) {
1378 | switchClockTo(PLAYER_B);
1379 | }
1380 | if (expanderPlayerBPressed) {
1381 | switchClockTo(PLAYER_A);
1382 | }

1383
1384 | if (btnScoreAPlus.wasPressed()) {
1385 | adjustScore(PLAYER_A, +1);
1386 | }
1387 | if (btnScoreAMinus.wasPressed()) {
1388 | adjustScore(PLAYER_A, -1);
1389 | }
1390 | if (btnScoreBPlus.wasPressed()) {
1391 | adjustScore(PLAYER_B, +1);
1392 | }
1393 | if (btnScoreBMinus.wasPressed()) {
1394 | adjustScore(PLAYER_B, -1);
1395 | }
1396 | }

1397
1398 | // After timeout or match over, select returns to menu so the device can reset.
1399 | if ((mode == MODE_TIMEOUT || mode == MODE_MATCH_OVER) && btnSelect.wasPressed()) {
1400 | enterMenu();
1401 | }
1402 | }

1403
1404 | void handleTouch() {
1405 | const uint32_t TOUCH_RELEASE_GRACE_MS = 140;
1406 | const uint32_t TOUCH_REPEAT_GUARD_MS = 220;
1407 | const int16_t TOUCH_SWIPE_THRESHOLD = 32;

1408
1409 | TouchPoint point = readTouch();
1410 | uint32_t nowMs = millis();

1411
1412 | if (point.touched) {
1413 | touchLastX = point.x;
1414 | touchLastY = point.y;
1415 | if (point.y < touchMinY) {
1416 | touchMinY = point.y;
1417 | }
1418 | if (point.y > touchMaxY) {
1419 | touchMaxY = point.y;
1420 | }
1421 | touchLastSeenMs = nowMs;
1422 | lastTouchSeen = true;
1423 | if (!touchWasDown) {
1424 | touchWasDown = true;
1425 | touchStartX = point.x;
1426 | touchStartY = point.y;
1427 | touchMinY = point.y;
1428 | touchMaxY = point.y;
1429 | touchStartMs = nowMs;
1430 | }
1431 | return;
1432 | }

1433
1434 | if (!touchWasDown) {
1435 | return;
1436 | }

1437
1438 | // The GT911 can briefly report no touch while a finger is still moving.
1439 | // Waiting a moment here keeps swipes from being split into tiny taps.
1440 | if (nowMs - touchLastSeenMs < TOUCH_RELEASE_GRACE_MS) {
1441 | return;
1442 | }

1443
1444 | touchWasDown = false;
1445 | wakeActivity();

1446
1447 | if (nowMs - touchLastHandledMs < TOUCH_REPEAT_GUARD_MS) {
1448 | return;
1449 | }
1450 | touchLastHandledMs = nowMs;

1451
1452 if (mode == MODE_MENU || mode == MODE_LOG || mode == MODE_NAME_EDIT ||

1453 | mode == MODE_CLOCK_SET || mode == MODE_APPEARANCE) {
1454 | handleTouchTap(touchLastX, touchLastY);
1455 | return;
1456 | }

1457
1458 | int16_t dx = (int16_t)touchLastX - (int16_t)touchStartX;
1459 | int16_t upDistance = (int16_t)touchStartY - (int16_t)touchMinY;
1460 | int16_t downDistance = (int16_t)touchMaxY - (int16_t)touchStartY;
1461 | int16_t dy = (downDistance > upDistance) ? downDistance : -upDistance;
1462 | if (abs(dy) >= TOUCH_SWIPE_THRESHOLD && abs(dy) > abs(dx)) {
1463 | uint16_t gestureEndY = touchStartY;
1464 | if (dy > 0) {
1465 | uint32_t candidate = (uint32_t)touchStartY + (uint32_t)abs(dy);
1466 | gestureEndY = (candidate >= PANEL_HEIGHT) ? PANEL_HEIGHT - 1 : (uint16_t)candidate;
1467 | } else {
1468 | gestureEndY = (touchStartY > abs(dy)) ? touchStartY - abs(dy) : 0;
1469 | }
1470 | handleTouchSwipe(touchStartX, touchStartY, touchLastX, gestureEndY);
1471 | } else {
1472 | handleTouchTap(touchLastX, touchLastY);
1473 | }
1474 | }

1475
1476 | void handleTouchTap(uint16_t x, uint16_t y) {
1477 | if (mode == MODE_NAME_EDIT) {
1478 | handleNameEditorTap(x, y);
1479 | return;
1480 | }

1481
1482 | if (mode == MODE_CLOCK_SET) {
1483 | handleClockSettingsTap(x, y);
1484 | return;
1485 | }

1486
1487 | if (mode == MODE_APPEARANCE) {
1488 | handleAppearanceSettingsTap(x, y);
1489 | return;
1490 | }

1491
1492 | if (mode == MODE_CONFIRM_END_MATCH) {
1493 | handleEndMatchConfirmTap(x, y);
1494 | return;
1495 | }

1496
1497 | if (mode == MODE_LOG) {
1498 | if (LOG_BACK.containsPadded(x, y, 18, 14)) {
1499 | mode = MODE_MATCH;
1500 | markDisplayDirty();
1501 | return;
1502 | }
1503 | if (LOG_CLEAR.containsPadded(x, y, 18, 14)) {
1504 | clearMatchLog();
1505 | markDisplayDirty();
1506 | return;
1507 | }
1508 | return;
1509 | }

1510
1511 | if (mode == MODE_MENU) {
1512 | if (SETTINGS_BACK.containsPadded(x, y, 18, 14)) {
1513 | mode = MODE_MATCH;
1514 | markDisplayDirty();
1515 | return;
1516 | }

1517
1518 | if (SETTINGS_MATCH_MINUS.containsPadded(x, y, 40, 18) ||
1519 | SETTINGS_MATCH_ROW_MINUS.contains(x, y)) {
1520 | currentMenuItem = MENU_MATCH_TARGET;
1521 | changeMenuValue(-1);
1522 | return;
1523 | }
1524 | if (SETTINGS_MATCH_PLUS.containsPadded(x, y, 40, 18) ||
1525 | SETTINGS_MATCH_ROW_PLUS.contains(x, y)) {
1526 | currentMenuItem = MENU_MATCH_TARGET;
1527 | changeMenuValue(+1);
1528 | return;
1529 | }
1530 | if (SETTINGS_TIME_MINUS.containsPadded(x, y, 40, 18) ||
1531 | SETTINGS_TIME_ROW_MINUS.contains(x, y)) {
1532 | currentMenuItem = MENU_INITIAL_TIME;
1533 | changeMenuValue(-1);
1534 | return;
1535 | }
1536 | if (SETTINGS_TIME_PLUS.containsPadded(x, y, 40, 18) ||
1537 | SETTINGS_TIME_ROW_PLUS.contains(x, y)) {
1538 | currentMenuItem = MENU_INITIAL_TIME;

1539 | changeMenuValue(+1);
1540 | return;
1541 | }
1542 | if (SETTINGS_DELAY_MINUS.containsPadded(x, y, 40, 18) ||
1543 | SETTINGS_DELAY_ROW_MINUS.contains(x, y)) {
1544 | currentMenuItem = MENU_DELAY;
1545 | changeMenuValue(-1);
1546 | return;
1547 | }
1548 | if (SETTINGS_DELAY_PLUS.containsPadded(x, y, 40, 18) ||
1549 | SETTINGS_DELAY_ROW_PLUS.contains(x, y)) {
1550 | currentMenuItem = MENU_DELAY;
1551 | changeMenuValue(+1);
1552 | return;
1553 | }
1554 | if (SETTINGS_SCOPE_GAME.containsPadded(x, y, 18, 10)) {
1555 | timerScope = TIMER_BY_GAME;
1556 | playerA_time_remaining = startingClockMs();
1557 | playerB_time_remaining = startingClockMs();
1558 | markSettingsDirty();
1559 | markDisplayDirty();
1560 | return;
1561 | }
1562 | if (SETTINGS_SCOPE_MATCH.containsPadded(x, y, 18, 10)) {
1563 | timerScope = TIMER_BY_MATCH;
1564 | playerA_time_remaining = startingClockMs();
1565 | playerB_time_remaining = startingClockMs();
1566 | markSettingsDirty();
1567 | markDisplayDirty();
1568 | return;
1569 | }
1570 | if (SETTINGS_MODE_SIMPLE.containsPadded(x, y, 12, 10)) {
1571 | timingMode = SIMPLE_DELAY;
1572 | markSettingsDirty();
1573 | markDisplayDirty();
1574 | return;
1575 | }
1576 | if (SETTINGS_MODE_BRONSTEIN.containsPadded(x, y, 12, 10)) {
1577 | timingMode = BRONSTEIN_DELAY;
1578 | markSettingsDirty();
1579 | markDisplayDirty();
1580 | return;
1581 | }
1582 | if (SETTINGS_MODE_FISCHER.containsPadded(x, y, 12, 10)) {
1583 | timingMode = FISCHER_INCREMENT;
1584 | markSettingsDirty();
1585 | markDisplayDirty();
1586 | return;
1587 | }
1588 | if (SETTINGS_APPEARANCE.containsPadded(x, y, 10, 10)) {
1589 | mode = MODE_APPEARANCE;
1590 | markDisplayDirty();
1591 | return;
1592 | }
1593 | if (SETTINGS_CLOCK.containsPadded(x, y, 18, 14)) {
1594 | openClockSettings();
1595 | return;
1596 | }
1597 | if (SETTINGS_START.containsPadded(x, y, 18, 14)) {
1598 | resetMatch();
1599 | startNewGame();
1600 | mode = MODE_MATCH;
1601 | markDisplayDirty();
1602 | return;
1603 | }
1604 | if (SETTINGS_END.containsPadded(x, y, 18, 14)) {
1605 | resetMatch();
1606 | mode = MODE_MATCH;
1607 | markDisplayDirty();
1608 | return;
1609 | }
1610 | return;
1611 | }

1612
1613 | bool timerAHit = REGION_TIMER_A.containsPadded(x, y, 12, 14) ||
1614 | REGION_HEADER_A.containsPadded(x, y, 12, 10);
1615 | bool timerBHit = REGION_TIMER_B.containsPadded(x, y, 12, 14) ||
1616 | REGION_HEADER_B.containsPadded(x, y, 12, 10);

1617
1618 | if (!clock_running && REGION_HEADER_A.containsPadded(x, y, 12, 10)) {
1619 | openNameEditor(PLAYER_A);
1620 | return;
1621 | }

1622
1623 | if (!clock_running && REGION_HEADER_B.containsPadded(x, y, 12, 10)) {
1624 | openNameEditor(PLAYER_B);

1625 | return;
1626 | }

1627
1628 | if (mode == MODE_MATCH && REGION_LOG.contains(x, y)) {
1629 | mode = MODE_LOG;
1630 | markDisplayDirty();
1631 | return;
1632 | }

1633
1634 | if (mode == MODE_MATCH && (REGION_SETTINGS.contains(x, y) || REGION_MATCH_TARGET.contains(x, y))) {
1635 | enterMenu();
1636 | return;
1637 | }

1638
1639 | if (HIT_PLAY_PAUSE.contains(x, y)) {
1640 | togglePlayPause();
1641 | return;
1642 | }

1643
1644 | if (HIT_END_GAME.contains(x, y)) {
1645 | if (mode == MODE_TIMEOUT) {
1646 | mode = MODE_MATCH;
1647 | startNewGame();
1648 | return;
1649 | }
1650 | if (game_in_progress || clock_running) {
1651 | endCurrentGame();
1652 | }
1653 | return;
1654 | }

1655
1656 | if (HIT_END_MATCH.contains(x, y)) {
1657 | if (mode == MODE_MATCH_OVER) {
1658 | resetMatch();
1659 | startNewGame();
1660 | } else {
1661 | pauseClock();
1662 | mode = MODE_CONFIRM_END_MATCH;
1663 | markDisplayDirty();
1664 | }
1665 | return;
1666 | }

1667
1668 | if (timerAHit) {
1669 | switchClockTo(PLAYER_B);
1670 | return;
1671 | }

1672
1673 | if (timerBHit) {
1674 | switchClockTo(PLAYER_A);
1675 | return;
1676 | }

1677
1678 | if (!clock_running && REGION_SCORE_A.contains(x, y)) {
1679 | int delta = (y < REGION_SCORE_A.y + (REGION_SCORE_A.h / 2)) ? +1 : -1;
1680 | adjustScore(PLAYER_A, delta);
1681 | return;
1682 | }

1683
1684 | if (!clock_running && REGION_SCORE_B.contains(x, y)) {
1685 | int delta = (y < REGION_SCORE_B.y + (REGION_SCORE_B.h / 2)) ? +1 : -1;
1686 | adjustScore(PLAYER_B, delta);
1687 | return;
1688 | }
1689 | }

1690
1691 | void handleTouchSwipe(uint16_t startX, uint16_t startY, uint16_t endX, uint16_t endY) {
1692 | if ((mode != MODE_MATCH && mode != MODE_TIMEOUT) || clock_running) {
1693 | return;
1694 | }

1695
1696 | int delta = (endY < startY) ? +1 : -1;
1697 | bool scoreA = REGION_SCORE_A.contains(startX, startY);
1698 | bool scoreB = REGION_SCORE_B.contains(startX, startY);

1699
1700 | if (!scoreA && !scoreB) {
1701 | return;
1702 | }

1703
1704 | adjustScore(scoreA ? PLAYER_A : PLAYER_B, delta);
1705 | markDisplayDirty();
1706 | }

1707
1708 | void pauseClock() {
1709 | if (!clock_running || active_player == PLAYER_NONE) {
1710 | return;

1711 | }

1712
1713 | uint32_t nowMs = millis();
1714 | pausedTurnElapsedMs = nowMs - turnStartMs;
1715 | clock_running = false;
1716 | lastTickMs = nowMs;
1717 | markDisplayDirty();
1718 | }

1719
1720 | void resumeClock() {
1721 | if (clock_running || active_player == PLAYER_NONE || matchWinner != PLAYER_NONE || timeoutPlayer != PLAYER_NONE) {
1722 | return;
1723 | }

1724
1725 | uint32_t nowMs = millis();
1726 | turnStartMs = nowMs - pausedTurnElapsedMs;
1727 | lastTickMs = nowMs;
1728 | clock_running = true;
1729 | markDisplayDirty();
1730 | }

1731
1732 | void togglePlayPause() {
1733 | if (mode != MODE_MATCH) {
1734 | return;
1735 | }

1736
1737 | if (clock_running) {
1738 | pauseClock();
1739 | } else if (!game_in_progress) {
1740 | startNewGame();
1741 | } else {
1742 | resumeClock();
1743 | }
1744 | }

1745
1746 | void switchClockTo(Player nextPlayer) {
1747 | uint32_t nowMs = millis();

1748
1749 | if (mode != MODE_MATCH || matchWinner != PLAYER_NONE || timeoutPlayer != PLAYER_NONE) {
1750 | return;
1751 | }

1752
1753 | if (!game_in_progress) {
1754 | startNewGame();
1755 | }

1756
1757 | // Once the clock is running, only the active player’s own large button
1758 | // should end the turn. Presses on the inactive side are ignored so an
1759 | // accidental bump cannot reset the current player’s delay window.
1760 | if (clock_running && active_player == nextPlayer) {
1761 | return;
1762 | }

1763
1764 | if (clock_running && active_player != PLAYER_NONE && active_player != nextPlayer) {
1765 | if (!applyTurnElapsed(active_player, nowMs)) {
1766 | return;
1767 | }
1768 | }

1769
1770 | active_player = nextPlayer;
1771 | clock_running = true;
1772 | turnStartMs = nowMs;
1773 | pausedTurnElapsedMs = 0;
1774 | lastTickMs = nowMs;
1775 | markDisplayDirty();
1776 | }

1777
1778 | // ---------------------------------------------------------------------------
1779 | // Clock behavior
1780 | // ---------------------------------------------------------------------------
1781 | void updateClock() {
1782 | if (!clock_running || active_player == PLAYER_NONE) {
1783 | lastTickMs = millis();
1784 | return;
1785 | }

1786
1787 | uint32_t nowMs = millis();
1788 | uint32_t elapsedMs = nowMs - lastTickMs;
1789 | if (elapsedMs < 1000) {
1790 | return;
1791 | }

1792
1793 | uint32_t wholeSeconds = elapsedMs / 1000;
1794 | lastTickMs += wholeSeconds * 1000;
1795 | match_elapsed_seconds += wholeSeconds;

1796

1797 | if (visibleReserveMs(active_player, nowMs) == 0) {
1798 | uint32_t *remaining = reserveFor(active_player);
1799 | if (remaining != nullptr) {
1800 | *remaining = 0;
1801 | }
1802 | clock_running = false;
1803 | timeoutPlayer = active_player;
1804 | active_player = PLAYER_NONE;
1805 | if (crawford_active) {
1806 | markCrawfordUsed();
1807 | }
1808 | game_in_progress = false;
1809 | mode = MODE_TIMEOUT;
1810 | playTimeoutBeep();
1811 | markDisplayDirty();
1812 | return;
1813 | }

1814
1815 | // Low-time warning. The critical zone beeps more often.
1816 | uint32_t visibleSeconds = visibleReserveMs(active_player, nowMs) / 1000UL;
1817 | if (visibleSeconds <= LOW_TIME_WARNING_SECONDS) {
1818 | uint32_t interval = (visibleSeconds <= CRITICAL_TIME_WARNING_SECONDS) ? 1000UL : 5000UL;
1819 | if (nowMs - lastLowTimeBeepMs >= interval) {
1820 | beep(2200, 45);
1821 | lastLowTimeBeepMs = nowMs;
1822 | }
1823 | }
1824 | }

1825
1826 | void addIncrementTo(Player player) {
1827 | if (increment_seconds == 0) {
1828 | return;
1829 | }

1830
1831 | if (player == PLAYER_A) {
1832 | playerA_time_remaining += (uint32_t)increment_seconds * 1000UL;
1833 | } else if (player == PLAYER_B) {
1834 | playerB_time_remaining += (uint32_t)increment_seconds * 1000UL;
1835 | }
1836 | markDisplayDirty();
1837 | }

1838
1839 | bool applyTurnElapsed(Player player, uint32_t nowMs) {
1840 | uint32_t *reserve = reserveFor(player);
1841 | if (reserve == nullptr) {
1842 | return true;
1843 | }

1844
1845 | uint32_t elapsedMs = nowMs - turnStartMs;
1846 | uint32_t delayOrIncrementMs = (uint32_t)delay_seconds * 1000UL;
1847 | uint32_t deductionMs = 0;

1848
1849 | if (timingMode == FISCHER_INCREMENT) {
1850 | deductionMs = elapsedMs;
1851 | } else {
1852 | deductionMs = (elapsedMs > delayOrIncrementMs) ? (elapsedMs - delayOrIncrementMs) : 0;
1853 | }

1854
1855 | if (deductionMs >= *reserve) {
1856 | *reserve = 0;
1857 | clock_running = false;
1858 | timeoutPlayer = player;
1859 | active_player = PLAYER_NONE;
1860 | if (crawford_active) {
1861 | markCrawfordUsed();
1862 | }
1863 | game_in_progress = false;
1864 | mode = MODE_TIMEOUT;
1865 | playTimeoutBeep();
1866 | markDisplayDirty();
1867 | return false;
1868 | }

1869
1870 | *reserve -= deductionMs;
1871 | if (timingMode == FISCHER_INCREMENT) {
1872 | *reserve += delayOrIncrementMs;
1873 | }
1874 | return true;
1875 | }

1876
1877 | uint32_t visibleReserveMs(Player player, uint32_t nowMs) {
1878 | uint32_t *reserve = reserveFor(player);
1879 | if (reserve == nullptr) {
1880 | return 0;
1881 | }
1882 | if (active_player != player) {

1883 | return *reserve;
1884 | }

1885
1886 | uint32_t elapsedMs = 0;
1887 | if (clock_running) {
1888 | elapsedMs = nowMs - turnStartMs;
1889 | } else if (pausedTurnElapsedMs > 0) {
1890 | elapsedMs = pausedTurnElapsedMs;
1891 | } else {
1892 | return *reserve;
1893 | }

1894
1895 | uint32_t delayOrIncrementMs = (uint32_t)delay_seconds * 1000UL;
1896 | uint32_t deductionMs = 0;

1897
1898 | if (timingMode == SIMPLE_DELAY) {
1899 | deductionMs = (elapsedMs > delayOrIncrementMs) ? (elapsedMs - delayOrIncrementMs) : 0;
1900 | } else {
1901 | deductionMs = elapsedMs;
1902 | }

1903
1904 | return (deductionMs >= *reserve) ? 0 : (*reserve - deductionMs);
1905 | }

1906
1907 | uint32_t *reserveFor(Player player) {
1908 | if (player == PLAYER_A) {
1909 | return &playerA_time_remaining;
1910 | }
1911 | if (player == PLAYER_B) {
1912 | return &playerB_time_remaining;
1913 | }
1914 | return nullptr;
1915 | }

1916
1917 | uint32_t matchClockSeconds() {
1918 | return initial_time_seconds * (uint32_t)match_target;
1919 | }

1920
1921 | uint32_t startingClockMs() {
1922 | uint32_t seconds = (timerScope == TIMER_BY_MATCH) ? matchClockSeconds() : initial_time_seconds;
1923 | return seconds * 1000UL;
1924 | }

1925
1926 | // ---------------------------------------------------------------------------
1927 | // Score and match state
1928 | // ---------------------------------------------------------------------------
1929 | void adjustScore(Player player, int delta) {
1930 | if ((mode != MODE_MATCH && mode != MODE_TIMEOUT) || clock_running) {
1931 | return;
1932 | }

1933
1934 | bool scorerIsOpponentOfCrawfordPlayer =
1935 | (match_target > 1) &&
1936 | ((player == PLAYER_A && playerB_score == match_target - 1) ||
1937 | (player == PLAYER_B && playerA_score == match_target - 1));

1938
1939 | if (delta > 0 && (crawford_active || scorerIsOpponentOfCrawfordPlayer)) {
1940 | // Any score recorded during the Crawford game ends Crawford immediately.
1941 | // Also catch the real scoreboard pattern: the one-away player did not
1942 | // score, so the opponent’s score changed and the next game is post-Crawford.
1943 | markCrawfordUsed();
1944 | }

1945
1946 | if (delta > 0 && game_in_progress) {
1947 | // A positive score adjustment is treated as the end of the current game.
1948 | // Manual corrections with minus buttons do not advance Crawford state.
1949 | endCurrentGame();
1950 | }

1951
1952 | int *score = (player == PLAYER_A) ? &playerA_score : &playerB_score;
1953 | *score += delta;
1954 | if (*score < 0) {
1955 | *score = 0;
1956 | }
1957 | if (*score > match_target) {
1958 | *score = match_target;
1959 | }

1960
1961 | checkMatchState();
1962 | markDisplayDirty();

1963
1964 | if (matchWinner != PLAYER_NONE || mode == MODE_MATCH_OVER) {
1965 | return;
1966 | }

1967
1968 // New games are counted only when startNewGame() is explicitly called.

1969 | // Scoring corrections should not advance the game counter.
1970 | }

1971
1972 | void checkMatchState() {
1973 | if (playerA_score >= match_target || playerB_score >= match_target) {
1974 | matchWinner = (playerA_score >= match_target) ? PLAYER_A : PLAYER_B;
1975 | clock_running = false;
1976 | active_player = PLAYER_NONE;
1977 | game_in_progress = false;
1978 | recordMatchLog();
1979 | mode = MODE_MATCH_OVER;
1980 | playMatchOverBeep();
1981 | markDisplayDirty();
1982 | return;
1983 | }

1984
1985 | if (crawford_used) {
1986 | pending_crawford_next_game = false;
1987 | if (!crawford_active) {
1988 | post_crawford = true;
1989 | cube_enabled = true;
1990 | }
1991 | return;
1992 | }

1993
1994 | // Crawford is only meaningful for match targets above 1.
1995 | if (match_target > 1 && !crawford_used && !crawford_active) {
1996 | bool someoneAtCrawfordScore =
1997 | (playerA_score == match_target - 1) || (playerB_score == match_target - 1);

1998
1999 | pending_crawford_next_game = someoneAtCrawfordScore;
2000 | }
2001 | }

2002
2003 | void startNewGame() {
2004 | if (mode == MODE_MATCH_OVER) {
2005 | return;
2006 | }

2007
2008 | game_number++;
2009 | game_in_progress = true;
2010 | clock_running = false;
2011 | active_player = PLAYER_NONE;
2012 | timeoutPlayer = PLAYER_NONE;
2013 | if (timerScope == TIMER_BY_GAME) {
2014 | playerA_time_remaining = startingClockMs();
2015 | playerB_time_remaining = startingClockMs();
2016 | }
2017 | pausedTurnElapsedMs = 0;
2018 | lastLowTimeBeepMs = 0;

2019
2020 | if (pending_crawford_next_game && !crawford_used) {
2021 | crawford_active = true;
2022 | post_crawford = false;
2023 | cube_enabled = false;
2024 | pending_crawford_next_game = false;
2025 | } else if (crawford_used) {
2026 | crawford_active = false;
2027 | post_crawford = true;
2028 | cube_enabled = true;
2029 | } else {
2030 | crawford_active = false;
2031 | post_crawford = false;
2032 | cube_enabled = true;
2033 | }

2034
2035 | lastTickMs = millis();
2036 | turnStartMs = lastTickMs;
2037 | markDisplayDirty();
2038 | }

2039
2040 | void endCurrentGame() {
2041 | clock_running = false;
2042 | active_player = PLAYER_NONE;
2043 | pausedTurnElapsedMs = 0;

2044
2045 | if (crawford_active) {
2046 | markCrawfordUsed();
2047 | }

2048
2049 | game_in_progress = false;
2050 | markDisplayDirty();
2051 | }

2052
2053 | void markCrawfordUsed() {
2054 | crawford_active = false;

2055 | crawford_used = true;
2056 | post_crawford = true;
2057 | pending_crawford_next_game = false;
2058 | cube_enabled = true;
2059 | }

2060
2061 | void forceEndMatch() {
2062 | clock_running = false;
2063 | active_player = PLAYER_NONE;
2064 | pausedTurnElapsedMs = 0;
2065 | game_in_progress = false;

2066
2067 | matchWinner = (playerA_score == playerB_score) ? PLAYER_NONE :
2068 | ((playerA_score > playerB_score) ? PLAYER_A : PLAYER_B);
2069 | recordMatchLog();
2070 | mode = MODE_MATCH_OVER;
2071 | playMatchOverBeep();
2072 | markDisplayDirty();
2073 | }

2074
2075 | void resetMatch() {
2076 | playerA_score = 0;
2077 | playerB_score = 0;
2078 | playerA_time_remaining = startingClockMs();
2079 | playerB_time_remaining = startingClockMs();
2080 | match_elapsed_seconds = 0;
2081 | active_player = PLAYER_NONE;
2082 | clock_running = false;
2083 | pausedTurnElapsedMs = 0;
2084 | crawford_used = false;
2085 | crawford_active = false;
2086 | post_crawford = false;
2087 | cube_enabled = true;
2088 | game_number = 0;
2089 | timeoutPlayer = PLAYER_NONE;
2090 | matchWinner = PLAYER_NONE;
2091 | pending_crawford_next_game = false;
2092 | game_in_progress = false;
2093 | mode = MODE_MATCH;
2094 | markDisplayDirty();
2095 | }

2096
2097 | // ---------------------------------------------------------------------------
2098 | // Menu behavior
2099 | // ---------------------------------------------------------------------------
2100 | void enterMenu() {
2101 | clock_running = false;
2102 | active_player = PLAYER_NONE;
2103 | mode = MODE_MENU;
2104 | markDisplayDirty();
2105 | }

2106
2107 | void handleMenu() {
2108 | if (btnPlayerA.wasPressed() || btnUp.wasPressed()) {
2109 | changeMenuValue(+1);
2110 | }

2111
2112 | if (btnPlayerB.wasPressed() || btnDown.wasPressed()) {
2113 | changeMenuValue(-1);
2114 | }

2115
2116 | if (btnScoreAPlus.wasPressed() || btnScoreBPlus.wasPressed()) {
2117 | nextMenuItem();
2118 | }

2119
2120 | if (btnScoreAMinus.wasPressed() || btnScoreBMinus.wasPressed()) {
2121 | previousMenuItem();
2122 | }

2123
2124 | if (btnSelect.wasPressed()) {
2125 | if (currentMenuItem == MENU_START_MATCH) {
2126 | resetMatch();
2127 | startNewGame();
2128 | } else if (currentMenuItem == MENU_RESET_MATCH) {
2129 | resetMatch();
2130 | enterMenu();
2131 | } else {
2132 | nextMenuItem();
2133 | }
2134 | }
2135 | }

2136
2137 | void changeMenuValue(int delta) {
2138 | switch (currentMenuItem) {
2139 | case MENU_MATCH_TARGET: {
2140 | int index = findCurrentTargetIndex();

2141 | index += delta;
2142 | if (index < 0) {
2143 | index = MATCH_TARGET_COUNT - 1;
2144 | }
2145 | if (index >= MATCH_TARGET_COUNT) {
2146 | index = 0;
2147 | }
2148 | match_target = MATCH_TARGETS[index];
2149 | playerA_time_remaining = startingClockMs();
2150 | playerB_time_remaining = startingClockMs();
2151 | markSettingsDirty();
2152 | break;
2153 | }

2154
2155 | case MENU_INITIAL_TIME: {
2156 | int32_t next = (int32_t)initial_time_seconds + (delta * 30);
2157 | if (next < 60) {
2158 | next = 60;
2159 | }
2160 | if (next > 99L * 60L) {
2161 | next = 99L * 60L;
2162 | }
2163 | initial_time_seconds = (uint32_t)next;
2164 | playerA_time_remaining = startingClockMs();
2165 | playerB_time_remaining = startingClockMs();
2166 | markSettingsDirty();
2167 | break;
2168 | }

2169
2170 | case MENU_DELAY: {
2171 | int next = (int)delay_seconds + delta;
2172 | if (next < 0) {
2173 | next = 0;
2174 | }
2175 | if (next > 60) {
2176 | next = 60;
2177 | }
2178 | delay_seconds = (uint8_t)next;
2179 | markSettingsDirty();
2180 | break;
2181 | }

2182
2183 | case MENU_INCREMENT: {
2184 | int next = (int)increment_seconds + delta;
2185 | if (next < 0) {
2186 | next = 0;
2187 | }
2188 | if (next > 60) {
2189 | next = 60;
2190 | }
2191 | increment_seconds = (uint8_t)next;
2192 | markSettingsDirty();
2193 | break;
2194 | }

2195
2196 | case MENU_BRIGHTNESS: {
2197 | int next = (int)brightness + (delta * 15);
2198 | if (next < 15) {
2199 | next = 15;
2200 | }
2201 | if (next > 255) {
2202 | next = 255;
2203 | }
2204 | brightness = (uint8_t)next;
2205 | setBrightness(brightness);
2206 | markSettingsDirty();
2207 | break;
2208 | }

2209
2210 | default:
2211 | break;
2212 | }
2213 | markDisplayDirty();
2214 | }

2215
2216 | void nextMenuItem() {
2217 | currentMenuItem = (MenuItem)(((uint8_t)currentMenuItem + 1) % MENU_COUNT);
2218 | markDisplayDirty();
2219 | }

2220
2221 | void previousMenuItem() {
2222 | uint8_t item = (uint8_t)currentMenuItem;
2223 | currentMenuItem = (MenuItem)((item == 0) ? (MENU_COUNT - 1) : (item - 1));
2224 | markDisplayDirty();
2225 | }

2226

2227 | uint8_t findCurrentTargetIndex() {
2228 | for (uint8_t i = 0; i < MATCH_TARGET_COUNT; i++) {
2229 | if (MATCH_TARGETS[i] == match_target) {
2230 | return i;
2231 | }
2232 | }
2233 | return 4; // Default to match to 9.
2234 | }

2235
2236 | // ---------------------------------------------------------------------------
2237 | // Display
2238 | // ---------------------------------------------------------------------------
2239 | void drawDisplay() {
2240 | bool modeChanged = !displayModeKnown || mode != lastDrawMode;
2241 | if (modeChanged) {
2242 | tft.fillScreen(uiBackgroundColor());
2243 | }
2244 | displayModeKnown = true;
2245 | lastDrawMode = mode;

2246
2247 | if (mode == MODE_NAME_EDIT) {
2248 | drawNameEditor();
2249 | return;
2250 | }

2251
2252 | if (mode == MODE_LOG) {
2253 | drawMatchLog();
2254 | return;
2255 | }

2256
2257 | if (mode == MODE_CLOCK_SET) {
2258 | drawClockSettings();
2259 | return;
2260 | }

2261
2262 | if (mode == MODE_APPEARANCE) {
2263 | drawAppearanceSettings();
2264 | return;
2265 | }

2266
2267 | if (mode == MODE_MENU) {
2268 | tft.setTextColor(TFT_TEXT, TFT_BACKGROUND);
2269 | tft.setTextSize(3);
2270 | tft.setCursor(248, 28);
2271 | tft.print("SETTINGS");

2272
2273 | tft.fillRect(SETTINGS_BACK.x, SETTINGS_BACK.y, SETTINGS_BACK.w, SETTINGS_BACK.h, TFT_PANEL);
2274 | tft.drawRoundRect(SETTINGS_BACK.x, SETTINGS_BACK.y, SETTINGS_BACK.w, SETTINGS_BACK.h, 6, TFT_BORDER);
2275 | tft.setTextSize(2);
2276 | tft.setCursor(44, 38);
2277 | tft.print("BACK");

2278
2279 | tft.fillRect(52, 82, 696, 58, TFT_PANEL);
2280 | tft.fillRect(52, 162, 696, 58, TFT_PANEL);
2281 | tft.fillRect(52, 242, 696, 58, TFT_PANEL);
2282 | tft.drawRoundRect(52, 82, 696, 58, 6, TFT_BORDER);
2283 | tft.drawRoundRect(52, 162, 696, 58, 6, TFT_BORDER);
2284 | tft.drawRoundRect(52, 242, 696, 58, 6, TFT_BORDER);

2285
2286 | tft.setTextColor(TFT_TEXT, TFT_PANEL);
2287 | tft.setTextSize(2);
2288 | tft.setCursor(76, 102);
2289 | tft.print("MATCH TARGET");
2290 | tft.setCursor(536, 102);
2291 | tft.printf("%d", match_target);

2292
2293 | tft.setCursor(76, 182);
2294 | tft.print("TIME / GAME");
2295 | tft.setCursor(520, 182);
2296 | tft.print(formatTime(initial_time_seconds));
2297 | tft.setTextColor(TFT_MUTED, TFT_PANEL);
2298 | tft.setTextSize(1);
2299 | tft.setCursor(76, 207);
2300 | tft.print("TOTAL ");
2301 | tft.print(formatTime(matchClockSeconds()));
2302 | tft.setTextColor(TFT_TEXT, TFT_PANEL);
2303 | tft.setTextSize(2);

2304
2305 | tft.setCursor(76, 262);
2306 | tft.print("BONUS / DELAY");
2307 | tft.setCursor(536, 262);
2308 | tft.printf("%u", delay_seconds);

2309
2310 | const Rect controls[] = {
2311 | SETTINGS_MATCH_MINUS, SETTINGS_MATCH_PLUS,
2312 | SETTINGS_TIME_MINUS, SETTINGS_TIME_PLUS,

2313 | SETTINGS_DELAY_MINUS, SETTINGS_DELAY_PLUS
2314 | };
2315 | const char *symbols[] = {"-", "+", "-", "+", "-", "+"};
2316 | for (uint8_t i = 0; i < 6; i++) {
2317 | tft.fillRect(controls[i].x, controls[i].y, controls[i].w, controls[i].h, TFT_PANEL_ALT);
2318 | tft.drawRoundRect(controls[i].x, controls[i].y, controls[i].w, controls[i].h, 6, TFT_BORDER);
2319 | tft.setTextColor(TFT_TEXT, TFT_PANEL_ALT);
2320 | tft.setTextSize(3);
2321 | tft.setCursor(controls[i].x + 40, controls[i].y + 14);
2322 | tft.print(symbols[i]);
2323 | }

2324
2325 | tft.setTextColor(TFT_TEXT, TFT_BACKGROUND);
2326 | tft.setTextSize(2);
2327 | tft.setCursor(76, 315);
2328 | tft.print("TIMER");
2329 | tft.fillRect(SETTINGS_SCOPE_GAME.x, SETTINGS_SCOPE_GAME.y, SETTINGS_SCOPE_GAME.w, SETTINGS_SCOPE_GAME.h,
2330 | timerScope == TIMER_BY_GAME ? TFT_OK : TFT_PANEL_ALT);
2331 | tft.drawRoundRect(SETTINGS_SCOPE_GAME.x, SETTINGS_SCOPE_GAME.y, SETTINGS_SCOPE_GAME.w, SETTINGS_SCOPE_GAME.h, 6, TFT_BORDER);
2332 | drawCenteredInRect("GAME", SETTINGS_SCOPE_GAME, 2, timerScope == TIMER_BY_GAME ? ILI9341_BLACK : TFT_TEXT,
2333 | timerScope == TIMER_BY_GAME ? TFT_OK : TFT_PANEL_ALT);
2334 | tft.fillRect(SETTINGS_SCOPE_MATCH.x, SETTINGS_SCOPE_MATCH.y, SETTINGS_SCOPE_MATCH.w, SETTINGS_SCOPE_MATCH.h,
2335 | timerScope == TIMER_BY_MATCH ? TFT_OK : TFT_PANEL_ALT);
2336 | tft.drawRoundRect(SETTINGS_SCOPE_MATCH.x, SETTINGS_SCOPE_MATCH.y, SETTINGS_SCOPE_MATCH.w, SETTINGS_SCOPE_MATCH.h, 6, TFT_BORDER);
2337 | drawCenteredInRect("MATCH", SETTINGS_SCOPE_MATCH, 2, timerScope == TIMER_BY_MATCH ? ILI9341_BLACK : TFT_TEXT,
2338 | timerScope == TIMER_BY_MATCH ? TFT_OK : TFT_PANEL_ALT);

2339
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

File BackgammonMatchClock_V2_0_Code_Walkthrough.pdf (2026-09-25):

# Portable Backgammon Match Clock V 2.0 Code Walkthrough

# Updated firmware analysis with detailed figures

# Target board: Elecrow CrowPanel ESP32 HMI 5.0-inch / DIS07050H

## Source file: BackgammonMatchClock(3).ino

# Firmware lines analyzed: 4104

Version label: | V 2.0
Focus: | Segment-by-segment explanation, hardware wiring, perfboard layout, UI feature map.
Output: | LaTeX source, PDF, images, and full code appendix.

This document is an engineering notebook for understanding, modifying, wiring, and maintaining the backgammon match clock firmware.

Backgammon Match Clock V 2.0 | Detailed Code Walkthrough

# Contents

1 Executive Summary | 2
2 What Changed in V 2.0 | 2
3 Detailed Figures | 2
4 Hardware Wiring and Pin Use | 8
5 Segment-by-Segment Code Walkthrough | 8
6 Top-Level Function Inventory | 59
7 Command/API Appendix | 67
A Full V 2.0 Source Code | 67

# 1 Executive Summary

This V 2.0 firmware implements a portable backgammon match clock and scoreboard for an 800 x 480 ESP32-S3 CrowPanel. The firmware combines match scoring, Crawford/post-Crawford rules, game/match timer scope, simple delay, Bronstein-style delay behavior, Fischer increment, touch UI, physical-button support through GPIO and PCF8575, persistent settings, player names, checker-color selection, match log storage, DS3231 real-time clock support, MAX17048 battery gauge support, splash graphics, and a custom RGB LCD drawing wrapper.

The main architectural pattern is: inputs change state; state marks the display dirty; the renderer redraws the current screen from that state. This keeps clock rules, match rules, hardware access, and drawing code mostly separated.

# 2 What Changed in V 2.0

Compared with the earlier versions, this source file is more visually developed. It adds or expands optional GFXfont support, compiled splash-image support, score/match-target font paths, checker-color selection during name editing, player-color persistence, and a clearer split between timer panels, score panels, and general UI text.
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

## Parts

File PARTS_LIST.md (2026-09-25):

# Backgammon Match Clock Parts List

This bill of materials matches the current ESP32-S3 firmware and enclosure
model. Quantities are for one complete clock. Amazon links intentionally open
search results where possible, since individual marketplace listings and seller
specifications change frequently.

## Core Electronics

| Qty | Part | What to look for | Amazon link | Status |
|---:|---|---|---|---|
| 1 | Elecrow CrowPanel ESP32-S3 5-inch HMI | Original 5-inch, 800x480 capacitive-touch CrowPanel with 8 MB PSRAM and battery connector | [Amazon search](https://www.amazon.com/s?k=Elecrow+CrowPanel+ESP32+5+inch+800x480) | [ ] |
| 1 | PCF8575 I2C 16-bit I/O expander | PCF8575 module, 2.5-5.5 V supply, address-select pads or jumpers | [Example module](https://www.amazon.com/dp/B0F2M5Y2LK) | [ ] |
| 1 | MAX17048 fuel-gauge breakout | MAX17048 module for one-cell LiPo/Li-ion; 3.3 V I2C-compatible | [Amazon search](https://www.amazon.com/s?k=MAX17048+LiPo+fuel+gauge+module) | [ ] |
| 1 | DS3231 RTC module | DS3231 module with I2C and backup-cell holder; use a 3.3 V-compatible board | [Amazon search](https://www.amazon.com/s?k=DS3231+RTC+module+3.3V) | [ ] |
| 1 | RTC backup cell | Match the RTC module holder, usually CR2032 | [Amazon search](https://www.amazon.com/s?k=CR2032+battery) | [ ] |

The current firmware expects these I2C addresses:

| Module | Expected address |
|---|---:|
| CrowPanel PCA9557 | `0x18`-`0x1F` |
| PCF8575 | `0x20`-`0x27` |
| MAX17048 | `0x36` |
| GT911 touch controller | Usually `0x5D` |
| DS3231 RTC | `0x68` |

## Buttons and Power Control

| Qty | Part | What to look for | Amazon link | Status |
|---:|---|---|---|---|
| 3 | Normally-open tactile switches | Momentary, through-hole, approximately 12 x 12 mm body; verify height before ordering | [Amazon search](https://www.amazon.com/s?k=12x12mm+momentary+tactile+push+button+through+hole) | [ ] |
| 1 | SPST slide power switch | Latching on/off switch; enclosure opening is currently 6 x 3 mm, so measure the selected switch before printing | [Amazon search](https://www.amazon.com/s?k=mini+SPST+slide+switch+6mm+3mm) | [ ] |

Physical-button assignments:

| Function | PCF8575 port |
|---|---:|
| Play/Pause | P00 |
| Player A | P01 |
| Player B | P07 |

Each button connects between its assigned PCF8575 port and GND. No external
resistor is required by the current active-low input arrangement.

The printable enclosure supplies custom button caps. Its current reference
geometry assumes approximately 12.5 x 12.5 x 7.3 mm switch bodies, 9.8 mm round
player-button openings, and a 34 x 12 mm opening beneath the rectangular
Play/Pause cap. Measure the switches you receive before printing the final case.

## Battery and Charging

| Qty | Part | What to look for | Amazon link | Status |
|---:|---|---|---|---|
| 1 | Protected one-cell LiPo battery | 3.7 V nominal, 4.2 V maximum, protection circuit, JST-PH 2-pin plug; maximum modeled envelope is about 55 x 55 x 8 mm | [Amazon search](https://www.amazon.com/s?k=3.7V+protected+LiPo+battery+JST+PH+2.0) | [ ] |
| 1 | USB-C power supply | Regulated 5 V, 2 A or greater, from a reputable manufacturer | [Amazon search](https://www.amazon.com/s?k=5V+2A+USB+C+power+adapter) | [ ] |
| 1 | USB-C data cable | Data-capable cable for programming and external power | [Amazon search](https://www.amazon.com/s?k=USB+C+data+cable) | [ ] |

The specified CrowPanel has a BAT input and onboard one-cell charging circuit;
Elecrow specifies a 3.7-4.2 V battery and 5 V/2 A external supply. Do not add a
second charger in parallel unless its power-path design has been reviewed.
The MAX17048 only measures battery voltage/state of charge and does not charge
the battery.

**Before connecting a battery:** check the connector polarity with a multimeter.
JST cable colors and connector orientation are not guaranteed between sellers.
BAT+ must reach battery positive and BAT- must reach battery negative.

## Wiring and Assembly

| Qty | Part | What to look for | Amazon link | Status |
|---:|---|---|---|---|
| 1 | I2C splitter/hub | Passive 4-pin I2C hub compatible with 3.3 V; it does not create additional buses | [Amazon search](https://www.amazon.com/s?k=Qwiic+I2C+hub+splitter) | [ ] |
| 1 set | 4-pin I2C cables | Match the connectors on the selected modules; confirm pin order for GND/VCC/SDA/SCL | [Amazon search](https://www.amazon.com/s?k=JST+SH+4+pin+Qwiic+cable+kit) | [ ] |
| 1 | Prototype PCB | Solderable perfboard or stripboard sized for the enclosure | [Amazon search](https://www.amazon.com/s?k=solderable+prototype+PCB+perfboard) | [ ] |
| 1 kit | Hook-up wire | 22-26 AWG stranded wire for short internal connections | [Amazon search](https://www.amazon.com/s?k=22+24+26+AWG+stranded+hookup+wire+kit) | [ ] |
| 1 kit | Pin headers | 2.54 mm male/female breakaway headers | [Amazon search](https://www.amazon.com/s?k=2.54mm+breakaway+pin+header+kit) | [ ] |
| 1 kit | Heat-shrink tubing | Assorted small diameters for switch and power joints | [Amazon search](https://www.amazon.com/s?k=heat+shrink+tubing+assortment+electronics) | [ ] |
| 1 roll | Foam mounting tape | Thin, strong double-sided tape for the battery and modules | [Amazon search](https://www.amazon.com/s?k=thin+double+sided+foam+tape+electronics) | [ ] |
| 1 | Inline fuse or resettable fuse | Optional protection in the battery/load path; size for the final measured current | [Amazon search](https://www.amazon.com/s?k=inline+resettable+fuse+holder+low+voltage) | [ ] |

## Enclosure Hardware

| Qty | Part | What to look for | Amazon link | Status |
|---:|---|---|---|---|
| 1 set | M3 screws | Assorted M3 machine screws for the display and case | [Amazon search](https://www.amazon.com/s?k=M3+machine+screw+assortment) | [ ] |
| 1 set | M3 heat-set inserts | Brass inserts sized for the chosen print material and screw length | [Amazon search](https://www.amazon.com/s?k=M3+heat+set+inserts+3D+printing) | [ ] |
| 4 | Rubber feet | Small self-adhesive feet for the enclosure base | [Amazon search](https://www.amazon.com/s?k=small+self+adhesive+rubber+feet+electronics) | [ ] |
| 1 spool | PETG or PLA+ filament | PETG is preferable if the clock may be exposed to a warm car or direct sunlight | [Amazon search](https://www.amazon.com/s?k=1.75mm+PETG+filament) | [ ] |

## Tools and Consumables

These are workshop items rather than parts installed in the clock:

- [Temperature-controlled soldering iron](https://www.amazon.com/s?k=temperature+controlled+soldering+iron+electronics)
- [Lead-free or 63/37 electronics solder](https://www.amazon.com/s?k=electronics+solder+small+diameter)
- [No-clean flux pen](https://www.amazon.com/s?k=no+clean+flux+pen)
- [Digital multimeter](https://www.amazon.com/s?k=digital+multimeter+electronics)
- [Wire stripper and flush cutters](https://www.amazon.com/s?k=electronics+wire+stripper+flush+cutter)
- [Heat-set insert soldering tips](https://www.amazon.com/s?k=M3+heat+set+insert+soldering+tips)

## Recommended Purchase Order

1. Confirm the exact CrowPanel model and its battery connector polarity.
2. Buy and bench-test the PCF8575, MAX17048, and DS3231 on the shared I2C bus.
3. Buy switches and measure their bodies, stems, and mounting openings.
4. Update the enclosure dimensions if the purchased parts differ from the CAD
   reference geometry.
5. Select a protected LiPo that fits the measured enclosure and verify polarity.
6. Print the case only after a complete dry fit of the electronics.

## Compatibility Notes

- Power all shared I2C logic from 3.3 V and connect every module to common GND.
- Avoid modules with fixed 5 V I2C pull-ups; they can expose the ESP32-S3 pins to
  unsafe voltage.
- A passive I2C hub only provides duplicate connectors. It does not resolve
  address conflicts.
- Some inexpensive DS3231 boards contain a charging circuit intended for an
  LIR2032 rechargeable cell. Do not install a normal CR2032 in a module that
  actively charges its backup cell; inspect the board design or buy a module
  explicitly described as CR2032-safe.
- Marketplace titles are not reliable specifications. Confirm the chip marking,
  voltage range, dimensions, connector type, and pin order on the actual listing
  before purchasing.

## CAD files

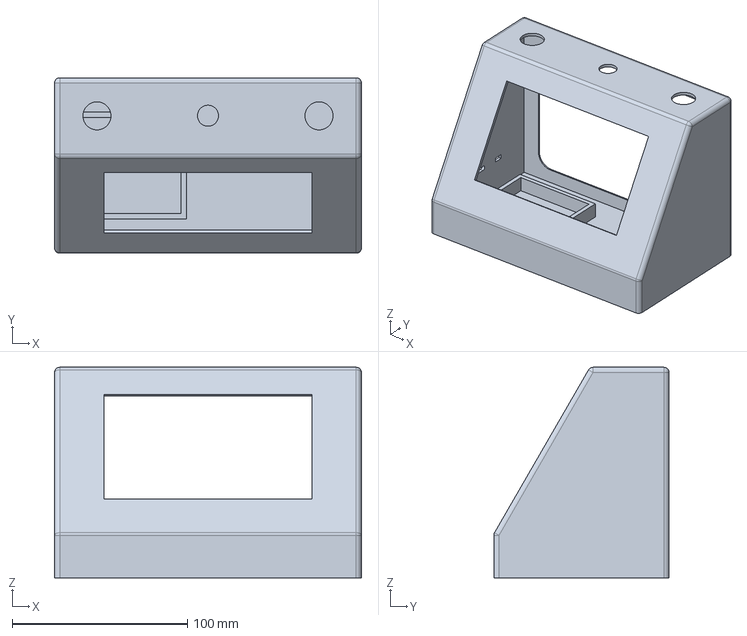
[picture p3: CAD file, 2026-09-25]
Case3D.FCStd
175.0 x 100.0 x 120.0 mm

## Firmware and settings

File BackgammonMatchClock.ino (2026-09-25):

/*
  Portable Backgammon Match Clock and Scoreboard
  Target: Elecrow CrowPanel ESP32 HMI 5.0-inch display (DIS07050H)

  Display library:
    This sketch uses the ESP32-S3 RGB LCD peripheral for the built-in 800x480
    RGB-parallel panel.

  Clock model:
    - At the start of each game, no clock is running.
    - Pressing Player A's large button ends A's turn and starts B's clock.
    - Pressing Player B's large button ends B's turn and starts A's clock.
    - Optional delay/increment is supported. Delay is Bronstein/simple delay:
      main time does not tick down until the active turn exceeds delaySeconds.
    - Increment, if enabled, is added to the player whose turn was ended.

  Crawford model:
    - When either player reaches match_target - 1 and Crawford has not been used,
      the following game is marked Crawford and the cube is disabled.
    - After that game ends, all later games are post-Crawford and cube is enabled.
*/

#include <Arduino.h>
#include <Wire.h>
#include <stdarg.h>
#include <Preferences.h>
#include <esp_sleep.h>
#include <esp_heap_caps.h>
#include <esp_lcd_panel_ops.h>
#include <esp_lcd_panel_rgb.h>
#include "splash_image.h"

#if __has_include(<gfxfont.h>)
#include <gfxfont.h>
#else
typedef struct {
  uint16_t bitmapOffset;
  uint8_t width;
  uint8_t height;
  uint8_t xAdvance;
  int8_t xOffset;
  int8_t yOffset;
} GFXglyph;

typedef struct {
  uint8_t *bitmap;
  GFXglyph *glyph;
  uint16_t first;
  uint16_t last;
  uint16_t yAdvance;
} GFXfont;
#endif

#if __has_include("7segment48pt7b_numbers.h")
#include "7segment48pt7b_numbers.h"
#define BGMC_HAS_CLOCK_FONT 1
#define BGMC_CLOCK_FONT SevenSegment48pt7bNumbers
#elif __has_include("Seven_Segment48pt7b_numbers.h")
#include "Seven_Segment48pt7b_numbers.h"
#define BGMC_HAS_CLOCK_FONT 1
#define BGMC_CLOCK_FONT Seven_Segment48pt7bNumbers
#elif __has_include("Seven_Segment48pt7b.h")
#include "Seven_Segment48pt7b.h"
#define BGMC_HAS_CLOCK_FONT 1
#define BGMC_CLOCK_FONT Seven_Segment48pt7b
#elif __has_include("Seven_Segment24pt7b.h")
#include "Seven_Segment24pt7b.h"
#define BGMC_HAS_CLOCK_FONT 1
#define BGMC_CLOCK_FONT Seven_Segment24pt7b
#elif __has_include("FreeMonoBold24pt7b.h")
#include "FreeMonoBold24pt7b.h"
#define BGMC_HAS_CLOCK_FONT 1
#define BGMC_CLOCK_FONT FreeMonoBold24pt7b
#elif __has_include(<Fonts/FreeMonoBold24pt7b.h>)
#include <Fonts/FreeMonoBold24pt7b.h>
#define BGMC_HAS_CLOCK_FONT 1
#define BGMC_CLOCK_FONT FreeMonoBold24pt7b
#else
#define BGMC_HAS_CLOCK_FONT 0
#endif

#if __has_include("FreeSans18pt7b.h")
#include "FreeSans18pt7b.h"
#define BGMC_HAS_UI_FONT 1
#elif __has_include(<Fonts/FreeSans18pt7b.h>)
#include <Fonts/FreeSans18pt7b.h>
#define BGMC_HAS_UI_FONT 1
#else
#define BGMC_HAS_UI_FONT 0
#endif

#if __has_include("FreeSans12pt7b.h")
#include "FreeSans12pt7b.h"
#define BGMC_HAS_SMALL_UI_FONT 1
#elif __has_include(<Fonts/FreeSans12pt7b.h>)
#include <Fonts/FreeSans12pt7b.h>
#define BGMC_HAS_SMALL_UI_FONT 1
#else
#define BGMC_HAS_SMALL_UI_FONT 0
#endif

#if __has_include("FreeSansBold96pt7b.h")
#include "FreeSansBold96pt7b.h"
#define BGMC_HAS_SCORE_96_FONT 1
#elif __has_include(<Fonts/FreeSansBold96pt7b.h>)
#include <Fonts/FreeSansBold96pt7b.h>
#define BGMC_HAS_SCORE_96_FONT 1
#else
#define BGMC_HAS_SCORE_96_FONT 0
#endif

#if __has_include("collegeb96pt7b_numbers.h")
#include "collegeb96pt7b_numbers.h"
#define BGMC_HAS_COLLEGE_SCORE_FONT 1
#define BGMC_COLLEGE_SCORE_FONT collegeb96pt7bNumbers
#elif __has_include("college96pt7b_numbers.h")
#include "college96pt7b_numbers.h"
#define BGMC_HAS_COLLEGE_SCORE_FONT 1
#define BGMC_COLLEGE_SCORE_FONT college96pt7bNumbers
#elif __has_include("collegeb96pt7b.h")
#include "collegeb96pt7b.h"
#define BGMC_HAS_COLLEGE_SCORE_FONT 1
#define BGMC_COLLEGE_SCORE_FONT collegeb96pt7b
#else
#define BGMC_HAS_COLLEGE_SCORE_FONT 0
#endif

#if __has_include("FreeSansBold48pt7b_numbers.h")
#include "FreeSansBold48pt7b_numbers.h"
#define BGMC_HAS_MATCH_TARGET_48_FONT 1
#define BGMC_MATCH_TARGET_48_FONT FreeSansBold48pt7bNumbers
#elif __has_include("FreeSansBold48pt7b.h")
#include "FreeSansBold48pt7b.h"
#define BGMC_HAS_MATCH_TARGET_48_FONT 1
#define BGMC_MATCH_TARGET_48_FONT FreeSansBold48pt7b
#elif __has_include(<Fonts/FreeSansBold48pt7b.h>)
#include <Fonts/FreeSansBold48pt7b.h>
#define BGMC_HAS_MATCH_TARGET_48_FONT 1
#define BGMC_MATCH_TARGET_48_FONT FreeSansBold48pt7b
#else
#define BGMC_HAS_MATCH_TARGET_48_FONT 0
#endif

#if __has_include("FreeSansBold24pt7b.h")
#include "FreeSansBold24pt7b.h"
#define BGMC_HAS_SCORE_FONT 1
#elif __has_include(<Fonts/FreeSansBold24pt7b.h>)
#include <Fonts/FreeSansBold24pt7b.h>
#define BGMC_HAS_SCORE_FONT 1
#else
#define BGMC_HAS_SCORE_FONT 0
#endif

// ---------------------------------------------------------------------------
// DIS07050H display-first pin map. External buttons can be added later on
// available expansion pins; avoid the LCD RGB bus pins below.
// ---------------------------------------------------------------------------
static const uint8_t PIN_PLAYER_A_BUTTON = 38; // GPIO_D IO38: one-button clock toggle to GND.
static const uint8_t PIN_PLAYER_B_BUTTON = 255;
static const uint8_t PIN_SCORE_A_PLUS = 255;
static const uint8_t PIN_SCORE_A_MINUS = 255;
static const uint8_t PIN_SCORE_B_PLUS = 255;
static const uint8_t PIN_SCORE_B_MINUS = 255;
static const uint8_t PIN_MENU_SELECT = 255;
static const uint8_t PIN_MENU_UP = 255;
static const uint8_t PIN_MENU_DOWN = 255;
static const uint8_t PIN_BUZZER = 255;
static const uint8_t PIN_TFT_BACKLIGHT = 2;
static const uint8_t PIN_BATTERY_ADC = 255;
static const uint8_t PIN_CHARGE_DETECT = 255; // Optional charger STAT pin, active-low when wired.

static const uint16_t PANEL_WIDTH = 800;
static const uint16_t PANEL_HEIGHT = 480;
static const uint8_t PIN_LCD_D0 = 8;
static const uint8_t PIN_LCD_D1 = 3;
static const uint8_t PIN_LCD_D2 = 46;
static const uint8_t PIN_LCD_D3 = 9;
static const uint8_t PIN_LCD_D4 = 1;
static const uint8_t PIN_LCD_D5 = 5;
static const uint8_t PIN_LCD_D6 = 6;
static const uint8_t PIN_LCD_D7 = 7;
static const uint8_t PIN_LCD_D8 = 15;
static const uint8_t PIN_LCD_D9 = 16;
static const uint8_t PIN_LCD_D10 = 4;
static const uint8_t PIN_LCD_D11 = 45;
static const uint8_t PIN_LCD_D12 = 48;
static const uint8_t PIN_LCD_D13 = 47;
static const uint8_t PIN_LCD_D14 = 21;
static const uint8_t PIN_LCD_D15 = 14;
static const uint8_t PIN_LCD_DE = 40;
static const uint8_t PIN_LCD_VSYNC = 41;
static const uint8_t PIN_LCD_HSYNC = 39;
static const uint8_t PIN_LCD_PCLK = 0;
static const uint8_t PIN_I2C_SDA = 19;
static const uint8_t PIN_I2C_SCL = 20;
static const uint8_t PCF8575_PLAY_PAUSE_PIN = 0; // PCF8575 P00, button to GND.
static const uint8_t PCF8575_PLAYER_A_PIN = 1; // PCF8575 P01, button to GND.
static const uint8_t PCF8575_PLAYER_B_PIN = 7; // PCF8575 P07, button to GND.
static const uint8_t MAX17048_I2C_ADDRESS = 0x36;
static const uint8_t DS3231_I2C_ADDRESS = 0x68;

// Rotary encoder placeholders. This sketch uses up/down buttons by default.
static const uint8_t PIN_ENCODER_A = 255;
static const uint8_t PIN_ENCODER_B = 255;

// Battery divider calibration placeholders.
static const float BATTERY_ADC_REF_VOLTS = 3.30f;
static const float BATTERY_DIVIDER_RATIO = 2.00f; // Vbat = Vadc * ratio.
static const float BATTERY_EMPTY_VOLTS = 3.30f;
static const float BATTERY_FULL_VOLTS = 4.20f;

// Display/backlight defaults.
static const uint8_t DEFAULT_BRIGHTNESS = 210; // 0..255 PWM duty.
static const bool TFT_BACKLIGHT_ACTIVE_HIGH = true;
static const uint16_t ILI9341_BLACK = 0x0000;
static const uint16_t ILI9341_WHITE = 0xFFFF;
static const uint16_t ILI9341_RED = 0xF800;
static const uint16_t ILI9341_GREEN = 0x07E0;
static const uint16_t ILI9341_BLUE = 0x001F;
static const uint16_t ILI9341_CYAN = 0x07FF;
static const uint16_t ILI9341_YELLOW = 0xFFE0;
static const uint16_t TFT_BACKGROUND = ILI9341_BLACK;
static const uint16_t TFT_PANEL = 0x2104;
static const uint16_t TFT_PANEL_ALT = 0x3186;
static const uint16_t TFT_BORDER = 0x7BEF;
static const uint16_t TFT_BUTTON_BORDER = 0xD6BA;
static const uint16_t TFT_TEXT = ILI9341_WHITE;
static const uint16_t TFT_TEXT_DARK = ILI9341_BLACK;
static const uint16_t TFT_ACTIVE_TEXT = 0x4208;
static const uint16_t TFT_MUTED = 0xBDF7;
static const uint16_t TFT_ACCENT_A = ILI9341_CYAN;
static const uint16_t TFT_ACCENT_B = 0xFD20;
static const uint16_t TFT_MAGENTA = 0xF81F;
static const uint16_t TFT_WARN = ILI9341_YELLOW;
static const uint16_t TFT_DANGER = ILI9341_RED;
static const uint16_t TFT_OK = ILI9341_GREEN;
static const uint16_t TFT_TIMER_WARNING_BG = 0xFBCF; // Light red for the final 90 seconds.
static const uint16_t PLAYER_COLOR_RED = 0x7800;    // #7C0A02 approximated in RGB565.
static const uint16_t PLAYER_COLOR_BLUE = 0x194A;   // #1C2951 approximated in RGB565.
static const uint16_t PLAYER_COLOR_GREEN = 0x19A5;  // #1C352D approximated in RGB565.
static const uint16_t PLAYER_COLOR_YELLOW = 0xFD20; // #FFA700 approximated in RGB565.
static const uint16_t PLAYER_COLOR_GRAY = 0x4208;
static const uint16_t PLAYER_COLOR_WHITE = ILI9341_WHITE;

// Time behavior.
static const uint32_t DEFAULT_INITIAL_TIME_SECONDS = 15UL * 60UL;
static const uint8_t DEFAULT_DELAY_SECONDS = 12;
static const uint8_t DEFAULT_INCREMENT_SECONDS = 0;
static const uint32_t LOW_TIME_WARNING_SECONDS = 30;
static const uint32_t CRITICAL_TIME_WARNING_SECONDS = 10;
static const uint32_t SLEEP_AFTER_IDLE_MS = 10UL * 60UL * 1000UL;
static const uint32_t LCD_PIXEL_CLOCK_HZ = 20000000;
static const uint16_t LCD_BOUNCE_BUFFER_LINES = 10;
static const uint8_t PLAYER_NAME_MAX_LEN = 10;

// Debounce intervals. Large buttons stay snappy; score/menu buttons are slower.
static const uint16_t PLAYER_BUTTON_DEBOUNCE_MS = 25;
static const uint16_t SMALL_BUTTON_DEBOUNCE_MS = 90;
static const uint16_t DISPLAY_REFRESH_MS = 1000;
static const uint16_t SETTINGS_SAVE_DELAY_MS = 1500;
static const char *FIRMWARE_VERSION = "lcd-refresh-2026-06-07";
static const uint8_t MATCH_LOG_MAX_ENTRIES = 8;

void logLine(const char *message);
void logPrintf(const char *format, ...);

// ---------------------------------------------------------------------------
// Types
// ---------------------------------------------------------------------------
enum Player : uint8_t {
  PLAYER_A = 0,
  PLAYER_B = 1,
  PLAYER_NONE = 255
};

enum TimingMode : uint8_t {
  SIMPLE_DELAY,
  BRONSTEIN_DELAY,
  FISCHER_INCREMENT
};

enum TimerScope : uint8_t {
  TIMER_BY_GAME,
  TIMER_BY_MATCH
};

enum DisplayTheme : uint8_t {
  THEME_NIGHT,
  THEME_DAY
};

enum ScoreDisplayMode : uint8_t {
  SCORE_STANDARD,
  SCORE_POINTS_TO_WIN
};

enum DeviceMode : uint8_t {
  MODE_MENU,
  MODE_MATCH,
  MODE_MATCH_OVER,
  MODE_TIMEOUT,
  MODE_NAME_EDIT,
  MODE_LOG,
  MODE_CLOCK_SET,
  MODE_APPEARANCE,
  MODE_CONFIRM_END_MATCH
};

enum MenuItem : uint8_t {
  MENU_MATCH_TARGET,
  MENU_INITIAL_TIME,
  MENU_DELAY,
  MENU_INCREMENT,
  MENU_BRIGHTNESS,
  MENU_START_MATCH,
  MENU_RESET_MATCH,
  MENU_COUNT
};

struct DebouncedButton {
  uint8_t pin;
  bool activeLow;
  bool stablePressed;
  bool lastRawPressed;
  bool pressedEvent;
  uint32_t lastChangeMs;
  uint16_t debounceMs;

  void begin(uint8_t buttonPin, uint16_t debounce, bool useActiveLow = true) {
    pin = buttonPin;
    activeLow = useActiveLow;
    stablePressed = false;
    lastRawPressed = false;
    pressedEvent = false;
    lastChangeMs = 0;
    debounceMs = debounce;

    if (pin != 255) {
      pinMode(pin, activeLow ? INPUT_PULLUP : INPUT);
    }
  }

  void update(uint32_t nowMs) {
    pressedEvent = false;
    if (pin == 255) {
      return;
    }

    bool rawPressed = activeLow ? (digitalRead(pin) == LOW) : (digitalRead(pin) == HIGH);
    if (rawPressed != lastRawPressed) {
      lastRawPressed = rawPressed;
      lastChangeMs = nowMs;
    }

    if ((nowMs - lastChangeMs) >= debounceMs && rawPressed != stablePressed) {
      stablePressed = rawPressed;
      if (stablePressed) {
        pressedEvent = true;
      }
    }
  }

  bool wasPressed() const {
    return pressedEvent;
  }
};

struct ExpanderButton {
  uint8_t bit;
  bool stablePressed;
  bool lastRawPressed;
  bool pressedEvent;
  uint32_t lastChangeMs;
  uint16_t debounceMs;

  void begin(uint8_t expanderBit, uint16_t debounce) {
    bit = expanderBit;
    stablePressed = false;
    lastRawPressed = false;
    pressedEvent = false;
    lastChangeMs = 0;
    debounceMs = debounce;
  }

  void update(uint32_t nowMs, uint16_t portState) {
    pressedEvent = false;
    if (bit >= 16) {
      return;
    }

    bool rawPressed = (portState & (1U << bit)) == 0;
    if (rawPressed != lastRawPressed) {
      lastRawPressed = rawPressed;
      lastChangeMs = nowMs;
    }

    if ((nowMs - lastChangeMs) >= debounceMs && rawPressed != stablePressed) {
      stablePressed = rawPressed;
      if (stablePressed) {
        pressedEvent = true;
      }
    }
  }

  bool wasPressed() const {
    return pressedEvent;
  }
};

struct Rect {
  int16_t x;
  int16_t y;
  int16_t w;
  int16_t h;

  bool contains(int16_t px, int16_t py) const {
    return px >= x && py >= y && px < x + w && py < y + h;
  }

  bool containsPadded(int16_t px, int16_t py, int16_t padX, int16_t padY) const {
    return px >= x - padX && py >= y - padY && px < x + w + padX && py < y + h + padY;
  }
};

struct TouchPoint {
  bool touched;
  uint16_t x;
  uint16_t y;
};
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
void loop() {
  handleTouch();
  handleButtons();

  if (mode == MODE_MATCH) {
    updateClock();
  }

  saveSettingsIfNeeded();
  maybeSleep();

  uint32_t nowMs = millis();
  if (!displayDirty && nowMs - lastRtcStatusMs >= 1000UL) {
    bool rtcChanged = updateRtcStatusCache(false);
    if (rtcChanged && (mode == MODE_MATCH || mode == MODE_MATCH_OVER || mode == MODE_TIMEOUT)) {
      drawStatusBar();
    }
  }

  bool timeDisplayDue = (clock_running && nowMs - lastDisplayMs >= DISPLAY_REFRESH_MS);
  if (displayDirty) {
    drawDisplay();
    lastDisplayMs = nowMs;
    displayDirty = false;
  } else if (timeDisplayDue) {
    drawTimerPanels();
    lastDisplayMs = nowMs;
  }
}

// ---------------------------------------------------------------------------
// Button handling
// ---------------------------------------------------------------------------
void handleButtons() {
  uint32_t nowMs = millis();

  btnPlayerA.update(nowMs);
  btnPlayerB.update(nowMs);
  btnScoreAPlus.update(nowMs);
  btnScoreAMinus.update(nowMs);
  btnScoreBPlus.update(nowMs);
  btnScoreBMinus.update(nowMs);
  btnSelect.update(nowMs);
  btnUp.update(nowMs);
  btnDown.update(nowMs);

  uint16_t expanderState = (pcf8575Address == 0) ? 0xFFFF : pcf8575Read(pcf8575Address);
  expanderBtnPlayerA.update(nowMs, expanderState);
  expanderBtnPlayerB.update(nowMs, expanderState);
  expanderBtnPlayPause.update(nowMs, expanderState);

  bool gpioPlayerAPressed = btnPlayerA.wasPressed();
  bool gpioPlayerBPressed = btnPlayerB.wasPressed();
  bool expanderPlayerAPressed = expanderBtnPlayerA.wasPressed();
  bool expanderPlayerBPressed = expanderBtnPlayerB.wasPressed();
  bool expanderPlayPausePressed = expanderBtnPlayPause.wasPressed();

  if (expanderPlayPausePressed) {
    logPrintf("PCF8575 P00 Play/Pause pressed: mode=%u running=%s game=%s\n",
              (unsigned int)mode,
              clock_running ? "yes" : "no",
              game_in_progress ? "yes" : "no");
  }

  bool anyPress = gpioPlayerAPressed || gpioPlayerBPressed ||
                  expanderPlayerAPressed || expanderPlayerBPressed ||
                  expanderPlayPausePressed ||
                  btnScoreAPlus.wasPressed() || btnScoreAMinus.wasPressed() ||
                  btnScoreBPlus.wasPressed() || btnScoreBMinus.wasPressed() ||
                  btnSelect.wasPressed() || btnUp.wasPressed() || btnDown.wasPressed();

  if (anyPress) {
    wakeActivity();
    playButtonBeep();
  }

  if (mode == MODE_MENU) {
    handleMenu();
    return;
  }

  if (mode == MODE_NAME_EDIT) {
    if (btnSelect.wasPressed()) {
      mode = MODE_MATCH;
      editingNameFor = PLAYER_NONE;
      markDisplayDirty();
    }
    return;
  }

  if (mode == MODE_LOG) {
    if (btnSelect.wasPressed()) {
      mode = MODE_MATCH;
      markDisplayDirty();
    }
    return;
  }

  if (mode == MODE_APPEARANCE) {
    if (btnSelect.wasPressed()) {
      mode = MODE_MENU;
      markDisplayDirty();
    }
    return;
  }

  if (mode == MODE_CONFIRM_END_MATCH) {
    if (btnSelect.wasPressed()) {
      mode = MODE_MATCH;
      markDisplayDirty();
    }
    return;
  }

  // The menu/select button pauses or resumes menu access during a match.
  if (btnSelect.wasPressed()) {
    enterMenu();
    return;
  }

  if (mode == MODE_MATCH) {
    if (expanderPlayPausePressed) {
      togglePlayPause();
      return;
    }

    if (gpioPlayerAPressed) {
      if (clock_running && active_player == PLAYER_A) {
        switchClockTo(PLAYER_B);
      } else {
        switchClockTo(PLAYER_A);
      }
    }
    if (gpioPlayerBPressed) {
      switchClockTo(PLAYER_A);
    }
    if (expanderPlayerAPressed) {
      switchClockTo(PLAYER_B);
    }
    if (expanderPlayerBPressed) {
      switchClockTo(PLAYER_A);
    }

    if (btnScoreAPlus.wasPressed()) {
      adjustScore(PLAYER_A, +1);
    }
    if (btnScoreAMinus.wasPressed()) {
      adjustScore(PLAYER_A, -1);
    }
    if (btnScoreBPlus.wasPressed()) {
      adjustScore(PLAYER_B, +1);
    }
    if (btnScoreBMinus.wasPressed()) {
      adjustScore(PLAYER_B, -1);
    }
  }

  // After timeout or match over, select returns to menu so the device can reset.
  if ((mode == MODE_TIMEOUT || mode == MODE_MATCH_OVER) && btnSelect.wasPressed()) {
    enterMenu();
  }
}

void handleTouch() {
  const uint32_t TOUCH_RELEASE_GRACE_MS = 140;
  const uint32_t TOUCH_REPEAT_GUARD_MS = 220;
  const int16_t TOUCH_SWIPE_THRESHOLD = 32;

  TouchPoint point = readTouch();
  uint32_t nowMs = millis();

  if (point.touched) {
    touchLastX = point.x;
    touchLastY = point.y;
    if (point.y < touchMinY) {
      touchMinY = point.y;
    }
    if (point.y > touchMaxY) {
      touchMaxY = point.y;
    }
    touchLastSeenMs = nowMs;
    lastTouchSeen = true;
    if (!touchWasDown) {
      touchWasDown = true;
      touchStartX = point.x;
      touchStartY = point.y;
      touchMinY = point.y;
      touchMaxY = point.y;
      touchStartMs = nowMs;
    }
    return;
  }

  if (!touchWasDown) {
    return;
  }

  // The GT911 can briefly report no touch while a finger is still moving.
  // Waiting a moment here keeps swipes from being split into tiny taps.
  if (nowMs - touchLastSeenMs < TOUCH_RELEASE_GRACE_MS) {
    return;
  }

  touchWasDown = false;
  wakeActivity();

  if (nowMs - touchLastHandledMs < TOUCH_REPEAT_GUARD_MS) {
    return;
  }
  touchLastHandledMs = nowMs;

  if (mode == MODE_MENU || mode == MODE_LOG || mode == MODE_NAME_EDIT ||
      mode == MODE_CLOCK_SET || mode == MODE_APPEARANCE) {
    handleTouchTap(touchLastX, touchLastY);
    return;
  }

  int16_t dx = (int16_t)touchLastX - (int16_t)touchStartX;
  int16_t upDistance = (int16_t)touchStartY - (int16_t)touchMinY;
  int16_t downDistance = (int16_t)touchMaxY - (int16_t)touchStartY;
  int16_t dy = (downDistance > upDistance) ? downDistance : -upDistance;
  if (abs(dy) >= TOUCH_SWIPE_THRESHOLD && abs(dy) > abs(dx)) {
    uint16_t gestureEndY = touchStartY;
    if (dy > 0) {
      uint32_t candidate = (uint32_t)touchStartY + (uint32_t)abs(dy);
      gestureEndY = (candidate >= PANEL_HEIGHT) ? PANEL_HEIGHT - 1 : (uint16_t)candidate;
    } else {
      gestureEndY = (touchStartY > abs(dy)) ? touchStartY - abs(dy) : 0;
    }
    handleTouchSwipe(touchStartX, touchStartY, touchLastX, gestureEndY);
  } else {
    handleTouchTap(touchLastX, touchLastY);
  }
}
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
